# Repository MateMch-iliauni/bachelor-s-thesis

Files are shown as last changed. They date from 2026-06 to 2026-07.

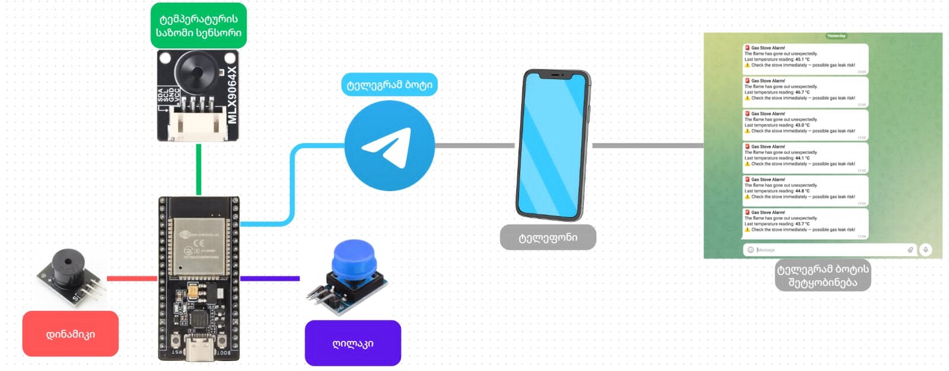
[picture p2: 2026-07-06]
final-website/assets/architecture.jpg

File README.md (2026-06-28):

# გაზქურის მონიტორინგის სისტემა

ეს არის "გაზქურის მონიტორინგის სისტემა"-ის ოფიციალური რეპოზიტორია,  საბაკალავრო ნაშრომი 2025-2026. სისტემა შექმნილია გაზქურის უსაფრთხოების მონიტორინგისა და დისტანციური შეტყობინებების მართვისთვის.

## პროექტის სტრუქტურა

რეპოზიტორია ორგანიზებულია შემდეგი საქაღალდეების მიხედვით:

- `Project-Codes/`: შეიცავს ESP32-S-ზე გაშვებულ firmware-ს, მათ შორის თერმული კამერის ღილაკის და ბაზერის მართვისა და Telegram bot-ის ლოგიკას.
- `project-diagrams/`: სისტემის არქიტექტურის დიაგრამები.
- `Production_drawings/`: პროექტის ტექნიკური ნახაზები და CAD ფაილები.
- `documentation/`: დოკუმენტაცია, მომხმარებლის სახელმძღვანელო.
- `Final-Presentation/`: საბოლოო პრეზენტაცია.
- `Attachments/`: დამატებითი ტექნიკური მასალები და კვლევითი ფაილები.

## სისტემის მახასიათებლები
- **აპარატურა:** ESP32-S მიკროკონტროლერი, 3-პინიანი KY-012 აქტიური ბაზერი თერმული კამერა და ღილაკი.
- **პროგრამული ლოგიკა:** თერმული კამერა, ბაზერი და Telegram bot-ის ლოგიკა გადანაწილებულია მრავალბირთვიან პროცესორზე.
- **ინტერფეისი:** დისტანციური შეტყობინებების მიღება Telegram Bot API-ს მეშვეობით.

## ავტორები
- მათე მჭედლიშვილი
- დათო ქადარია

---
*შექმნილია 2026 წელს, ილიას სახელმწიფო უნივერსიტეტის ფარგლებში.*

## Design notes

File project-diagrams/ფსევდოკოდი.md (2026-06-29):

// — გლობალური ცვლადები —
STATES = { IDLE, MONITORING, FIRE_ACTIVE, ALARM }
state ← IDLE
CONST FIRE_ON	<- 80°C
CONST FIRE_OFF	<- 55°C
CONST COLD_FRAMES_REQUIRED    	<- 8       // ~4 წმ @ 2 Hz
CONST COOLING_FRAMES_REQUIRED 	<- 10     // ~5 წმ @ 2 Hz
CONST COOLING_DELTA	<- -0.2°C
CONST BEEP_INTERVAL	<- 10 წმ

// — ინიციალიზაცია —
PROCEDURE Setup():
    init Serial, Buzzer(OFF), Button(INPUT_PULLUP)
    create tempQueue, alertQueue
    recover I2C bus
    IF NOT sensor.begin() THEN halt forever  // შეცდომა
    configure sensor (CHESS, 18-bit, 2 Hz)
    Setup_WiFi() // WiFiManager პორტალი -> დაკავშირება ან offline
    start task SensorTask   on core 1
    start task TelegramTask on core 0

// — მთავარი ნაკადი —
PROCEDURE Loop():
    Update_Buzzer() // ავტომატურად გამორთვა 500 მილიწამის შემდეგ
    IF Button_Pressed() THEN // debounce (20 მილიწამი)
        Stop_Buzzer()
        state ← (state == IDLE) ? MONITORING : IDLE
        reset counters and queues
        RETURN
    IF state == IDLE THEN RETURN
    IF NOT tempQueue.receive(maxTemp) THEN RETURN   // ახალი frame არ არის

    SWITCH state:
        CASE MONITORING:
            IF maxTemp ≥ FIRE_ON THEN
                state ← FIRE_ACTIVE
                peakTemp ← maxTemp ;  previousTemp ← maxTemp
                reset coldFrameCount, coolingFrames

        CASE FIRE_ACTIVE:
            peakTemp ← max(peakTemp, maxTemp)
            delta ← maxTemp − previousTemp
            IF delta ≤ COOLING_DELTA THEN coolingFrames++ ELSE coolingFrames ← 0
            previousTemp ← maxTemp

            // პირობა 1: მკვეთრი ვარდნა ზღვარს ქვემოთ
            IF maxTemp < FIRE_OFF THEN
                coldFrameCount++
                IF coldFrameCount ≥ COLD_FRAMES_REQUIRED THEN Raise_Alarm(maxTemp)
            ELSE
                coldFrameCount ← 0
            // პირობა 2: თანდათანობითი გაგრილების ტენდენცია (ცხელი ჭურჭელი)
            IF coolingFrames ≥ COOLING_FRAMES_REQUIRED THEN Raise_Alarm(maxTemp)

        CASE ALARM:
            IF (now − lastAlertTime) ≥ BEEP_INTERVAL THEN
                Start_Buzzer() ;  Trigger_Alert(maxTemp)   // განმეორებითი შეხსენება

PROCEDURE Raise_Alarm(t):
    state ← ALARM ;  lastAlertTime ← now
    Start_Buzzer()
    Trigger_Alert(t) // t ჩაიწერება alertQueue-ში

// — სენსორის ნაკადი (ბირთვი 1) —
TASK SensorTask():
    LOOP forever:
        IF state == IDLE THEN wait 50 ms ; CONTINUE
        IF sensor.getFrame(frame) fails THEN wait 20 ms ; CONTINUE
        maxT ← max(frame[0 … 767])           // 32×24 პიქსელის უმაღლესი მნიშვნელობა
        tempQueue.overwrite(maxT)           // ყოველთვის უახლესი კადრი
        wait 10 ms

// ── Telegram-ის ნაკადი (ბირთვი 0) ──
TASK TelegramTask():
    LOOP forever:
        IF alertQueue.receive(alert) THEN
            IF WiFi connected THEN
                bot.sendMessage(chatID, alarm_text(alert.temp))   // HTTPS/TLS
        wait 50 ms

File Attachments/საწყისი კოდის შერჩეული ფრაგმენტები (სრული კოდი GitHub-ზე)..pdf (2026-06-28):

ამ დანართში მოცემულია სისტემის საწყისი კოდის ყველაზე მნიშვნელოვანი ფრაგმენტები -სტატუსების უსაფრთხო მართვა (thread-safe getState/setState), სენსორისა და Telegram-ის ნაკადები (tasks) და ცეცხლის ჩაქრობის ამოცნობის ლოგიკა - მოკლე განმარტებებით. სრული კოდი ხელმისაწვდომია GitHub-ზე.

## სისტემის ძირითადი პარამეტრები

ქვემოთ მოცემულია ის ძირითადი პარამეტრები, რომელთა საფუძველზეც მუშაობს სისტემა: ცეცხლის ანთება/ჩაქრობის ტემპერატურული ზღვრები, ცეცხლის ჩაქრობის დასადასტურებლად საჭირო კადრების (frame-ების) რაოდენობა და Telegram-ზე შეტყობინების გასაგზავნად საჭირო მონაცემები.

const float | FIRE_ON_THRESHOLD = 80.0f;
const float | FIRE_OFF_THRESHOLD = 55.0f;
const int | COLD_FRAMES_REQUIRED = 8;
const int | COOLING_FRAMES_REQUIRED = 10;
const float | COOLING_DELTA_THRESHOLD = -0.2f;
const unsigned long BEEP_INTERVAL_MS = 10000UL; const unsigned long BEEP_DURATION_MS = 500UL;
const char* | TELEGRAM_BOT_TOKEN =
"7655520460:AAG239a4LqNq0acoINI3Pn9RyacG_6AhRUc";
String | TELEGRAM_CHAT_ID = "8154736889";

## სისტემის სტატუსები (state-ები) და ნაკადებზე უსაფრთხო წვდომა

ეს ფრაგმენტი წარმოადგენს პროგრამის ნაკადების (tasks) უსაფრთხო მართვის მექანიზმს.
სისტემას აქვს ოთხი სტატუსი (state): | უმოქმედობა (IDLE), | მონიტორინგი
(MONITORING), ცეცხლის დაფიქსირება (FIRE_ACTIVE) და განგაში (ALARM). ცვლადი currentState ინახავს მიმდინარე სტატუსს, getState() კითხულობს მას, ხოლო setState() უსაფრთხოდ ცვლის ერთ მდგომარეობას მეორით. stateMux კი კრძალავს ორი ნაკადის ერთდროულ წვდომას ამ ცვლადზე და ამით გამორიცხავს მონაცემთა კონფლიქტს - ეს მიიღწევა portENTER_CRITICAL() და portEXIT_CRITICAL() ფუნქციებით.

enum SystemState { STATE_IDLE, STATE_MONITORING, STATE_FIRE_ACTIVE, STATE_ALARM };

static SystemState currentState = STATE_IDLE;
static portMUX_TYPE stateMux = portMUX_INITIALIZER_UNLOCKED;

inline SystemState getState() { SystemState s;
portENTER_CRITICAL(&stateMux); s = currentState;
portEXIT_CRITICAL(&stateMux);
return s;
}

## თერმული კამერის მუშაობის მექანიზმი

სენსორის ფუნქცია გაშვებულია პროცესორის მეორე ბირთვზე (Core 1). იგი კითხულობს 768-პიქსელიან (32×24) ტემპერატურულ მატრიცას, პოულობს მასში მაქსიმალურ მნიშვნელობას და გადასცემს მას სისტემის ძირითად მაკონტროლებელ ლოგიკას რიგის (queue) მეშვეობით.

inline void setState(SystemState s) {
portENTER_CRITICAL(&stateMux);
currentState = s;
portEXIT_CRITICAL(&stateMux); }

void sensorTask(void* parameter) { while (true) {
if (getState() == STATE_IDLE) { vTaskDelay(50 / portTICK_PERIOD_MS); continue;
}

if (mlx.getFrame(sensorFrame) != 0) { Serial.println("[SENSOR] Frame read failed – retrying."); vTaskDelay(20 / portTICK_PERIOD_MS);
continue;
}

float maxT = sensorFrame[0];
for (int i = 1; i < 32 * 24; i++)
if (sensorFrame[i] > maxT) maxT = sensorFrame[i];

xQueueReset(tempQueue);

xQueueSend(tempQueue, &maxT, 0);

vTaskDelay(10 / portTICK_PERIOD_MS);
}
}

## ცეცხლის უეცარი ჩაქრობის ან ტემპერატურის თანდათანობითი ვარდნის დაფიქსირება

სისტემა ცეცხლის ჩაქრობას აფიქსირებს ორი პარალელური მეთოდით: (1) თუ ტემპერატურა ჩამოსცდება 55°C-ს; და (2) თუ ჭურჭელი ცხელ ტემპერატურას ინარჩუნებს, თუმცა შეინიშნება გაგრილების ტენდენცია: კადრებს შორის ტემპერატურის ვარდნა არის 0.2°C ან მეტი ზედიზედ რამდენიმე კადრის განმავლობაში.

case STATE_FIRE_ACTIVE: {
if (maxTemp > peakTemp) peakTemp = maxTemp;

float delta = maxTemp - previousTemp;

if (delta <= COOLING_DELTA_THRESHOLD) { coolingFrames++;
} else {
coolingFrames = 0;
}

previousTemp = maxTemp;

if (maxTemp < FIRE_OFF_THRESHOLD) { coldFrameCount++;
if (coldFrameCount >= COLD_FRAMES_REQUIRED) { setState(STATE_ALARM);
lastAlertTime = millis();
startBuzzer();
triggerAlert(maxTemp);
}
} else {
if (coldFrameCount > 0) {
coldFrameCount = 0;
}
}

if (coolingFrames >= COOLING_FRAMES_REQUIRED) { setState(STATE_ALARM);
lastAlertTime = millis();
startBuzzer();
triggerAlert(maxTemp);
}

break;
}

## Telegram-შეტყობინების გაგზავნა

შეტყობინების გაგზავნის ფუნქცია გაშვებულია პროცესორის პირველ ბირთვზე (Core 0) და დამოუკიდებლად ამუშავებს Telegram API-ის მოთხოვნებს. ამის წყალობით, თერმული კამერიდან მიღებული მონაცემების დამუშავება არ ფერხდება შეტყობინების გაგზავნის დროს.

void telegramTask(void* parameter) {
AlertData alert;
while (true) {
if (xQueueReceive(alertQueue, &alert, 0) == pdTRUE) { if (WiFi.status() == WL_CONNECTED) {
WiFiClientSecure localClient;
localClient.setInsecure();
UniversalTelegramBot bot(TELEGRAM_BOT_TOKEN, localClient);

String message = "🚨 *Gas Stove Alarm!*\n";
message += "The flame has gone out unexpectedly.\n";
message += "Last temperature reading: *" + String(alert.temp, 1) + " °C*\n"; message += "⚠️ Check the stove immediately — possible gas leak risk!";

Serial.println("[Telegram] Sending alert…"); bot.sendMessage(TELEGRAM_CHAT_ID, message, "Markdown"); Serial.println("[Telegram] Alert sent.");
} else {
Serial.println("[Telegram] Skipped – no Wi-Fi.");
}
}

vTaskDelay(50 / portTICK_PERIOD_MS); }
}

სრული კოდის github-ის ბმული: https://github.com/MateMch-iliauni/Project-Codes/blob/main/finalproject.ino

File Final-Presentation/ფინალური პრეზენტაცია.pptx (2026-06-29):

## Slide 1

გაზქურის მონიტორინგის სისტემა

დამამთავრებელი კურსის დიზანის პროექტი

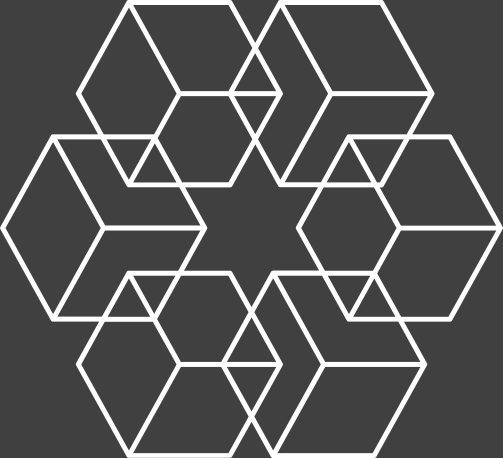
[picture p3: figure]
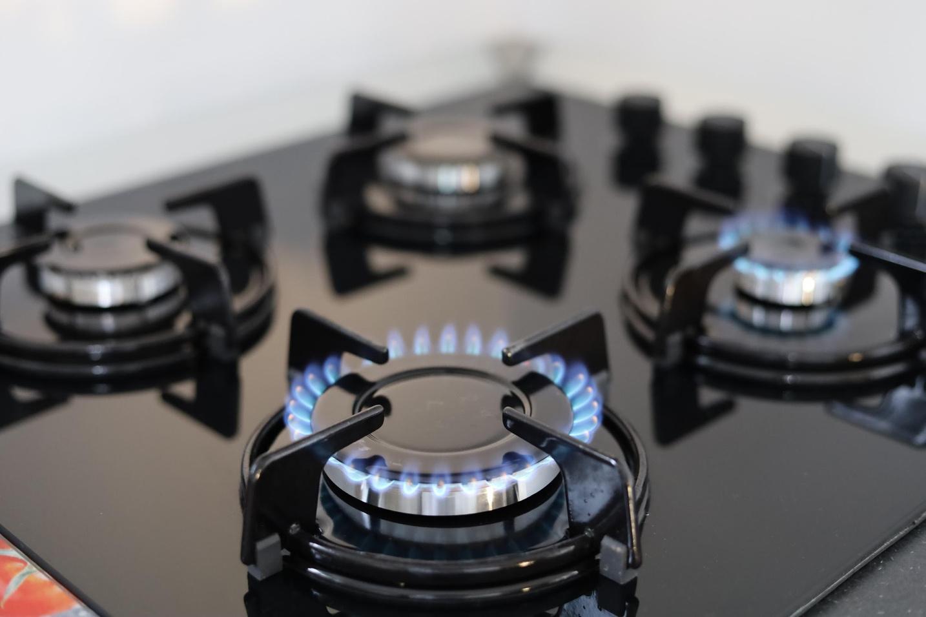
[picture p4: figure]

კურსის ხელმძღვანელები:
დავით ჩხაიძე
გიორგი მოდებაძე

ჯგუფის წევრები:
დათო ქადარია
მათე მჭედლიშვილი

1

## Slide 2

შევქმენით გაზქურის მონიტორინგის სისტემა, რომელიც თერმული კამერის გამოყენებით აღმოაჩენს ცეცხლის ჩაქრობას და მყისიერად ატყობინებს მომხმარებელს დინამიკისა და Telegram-ის მეშვეობით.

პროექტის მიმოხილვა

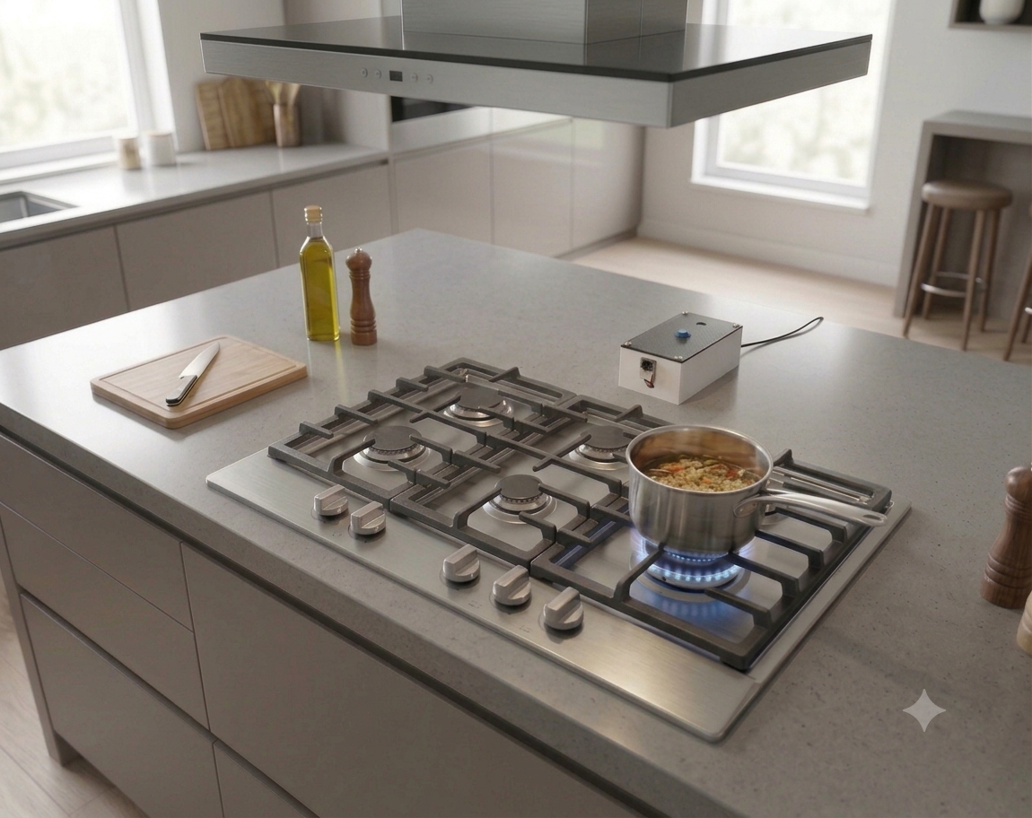
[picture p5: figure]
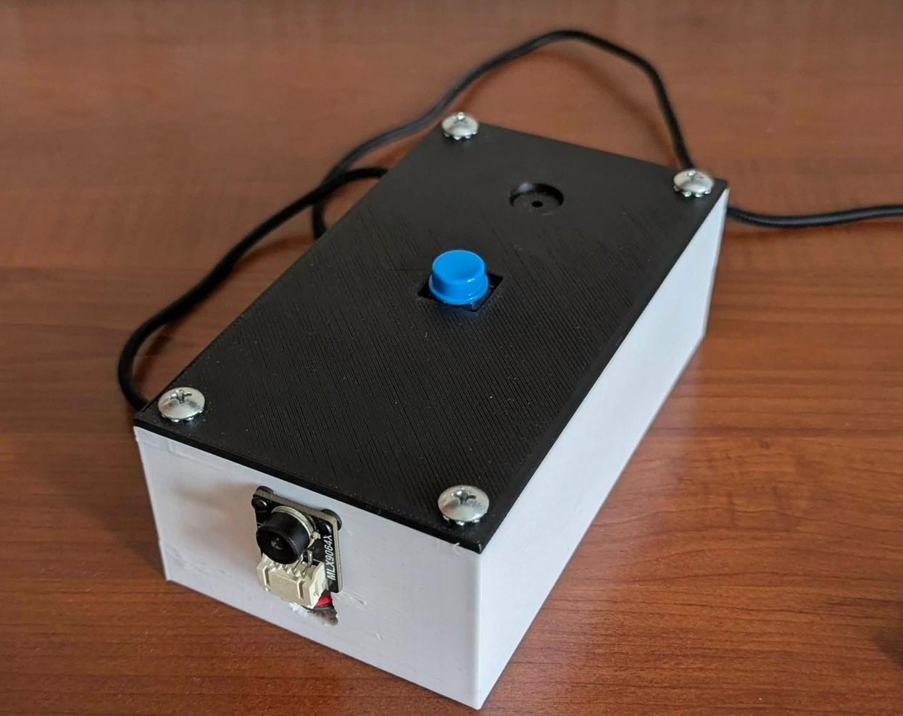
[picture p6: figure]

2

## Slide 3

ბლოკდიაგრამა

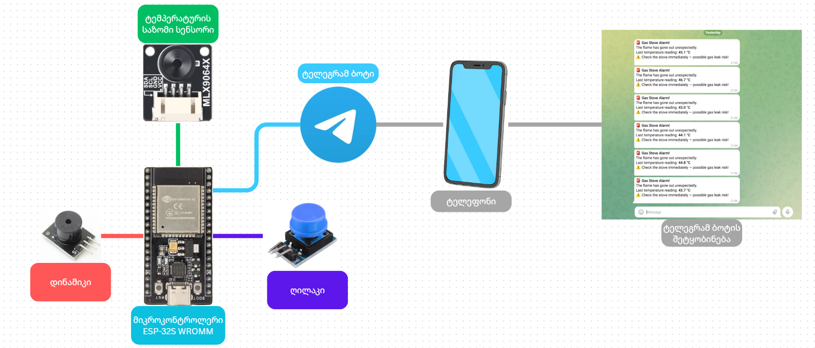
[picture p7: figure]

4

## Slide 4

ტემპერატურის სენსორი

MLX90640
    - თერმული კამერა, 110° ხედვის კუთხით, ზომავს -40℃～300℃
    - იყენებს I²C ინტერფეისს, რაც შესაძლებელს ხდის მის ინტეგრირებას ESP32

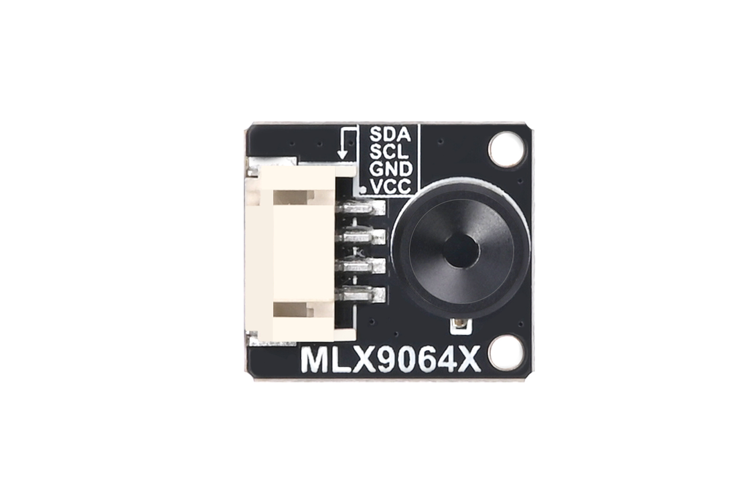
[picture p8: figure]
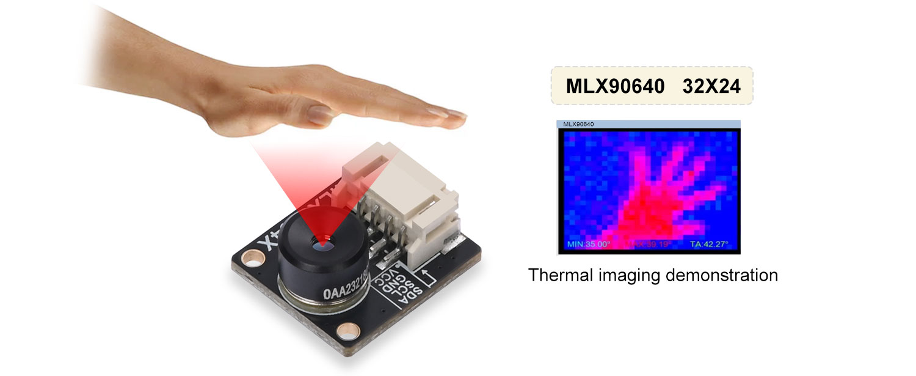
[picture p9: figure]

5

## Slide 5

ESP-32S WROOM
    - კომპაქტური და ძლიერი, მრავალფუნქციური მიკროკონტროლერი
    - უკაბელო კავშირის (Wi-Fi და Bluetooth) შესაძლებლობების მქონე მოწყობილობა, რომელიც ასევე გამორჩეულია ენერგოეფექტურობით.

მიკროკონტროლერი

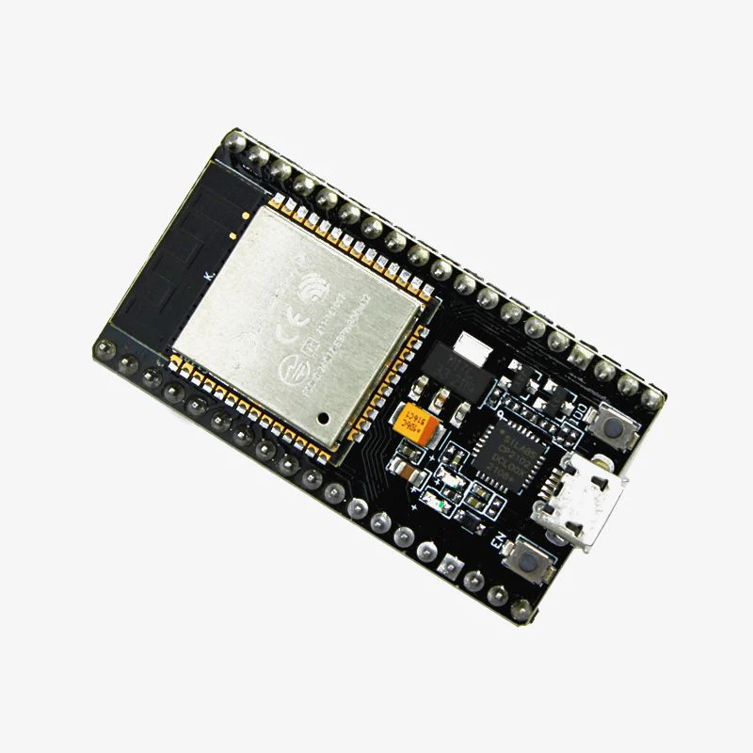
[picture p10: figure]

8

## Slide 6

    - კომპაქტური active buzzer-ი, რომელიც ჩართვისას გამოსცემს ფიქსირებული სიხშირის (~85 dB) სიგნალს, რაც საკმაოდ ეფექტურია ლოკალური შეტყობინებისთვის.

დინამიკი

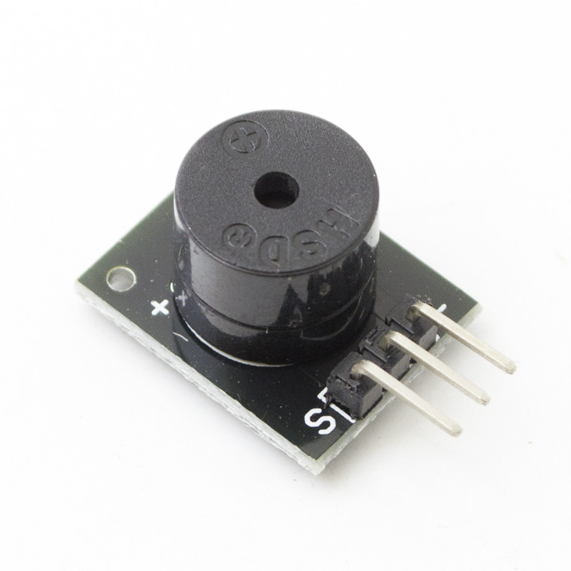
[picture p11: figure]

9

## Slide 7

  - ღილაკი აფიქსირებს დაჭერას და გადასცემს სიგნალს მიკროკონტროლერს, რითაც მოხდება სისტემის მართვა.

ღილაკი

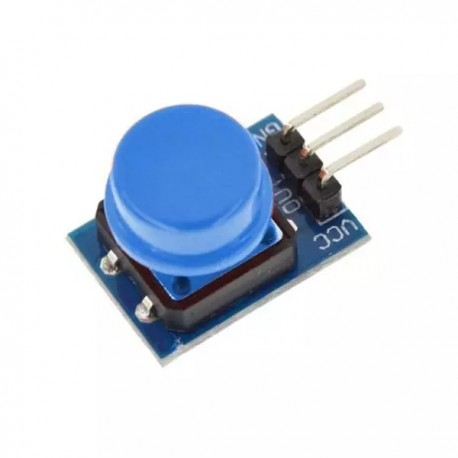
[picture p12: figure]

9

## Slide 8

3D დიზაინი, თერმული კამერა, დინამიკი, ღილაკი და მიკრო კონტროლერი ქმნის სრულ მოწყობილობას “გაზქირის მონიტორნიგის სისტემა”

პროტოტიპი

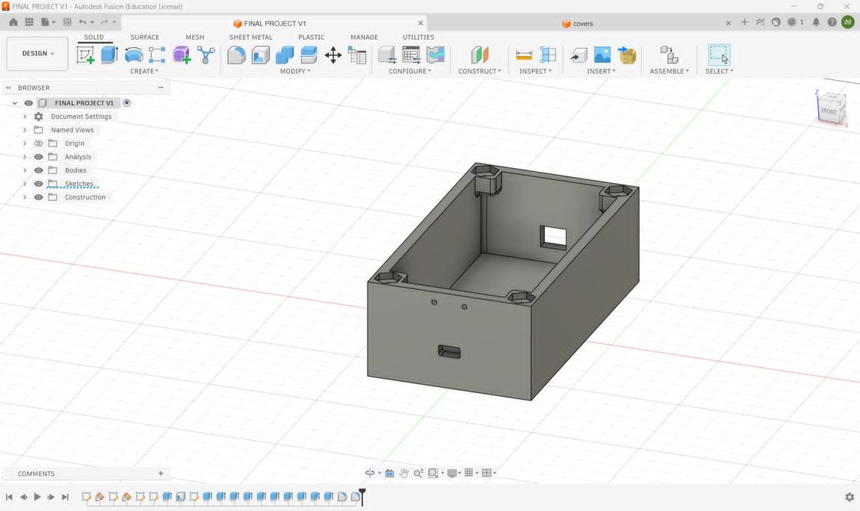
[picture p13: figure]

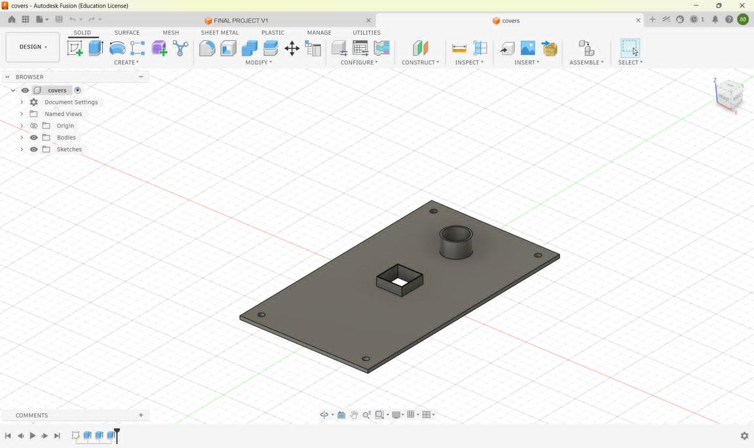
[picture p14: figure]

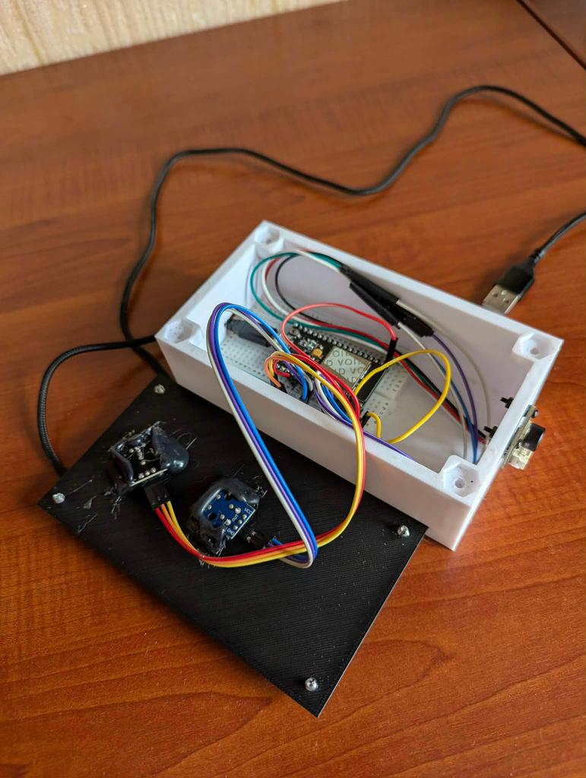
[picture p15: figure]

12

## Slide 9

მოქმედების მექანიზმი

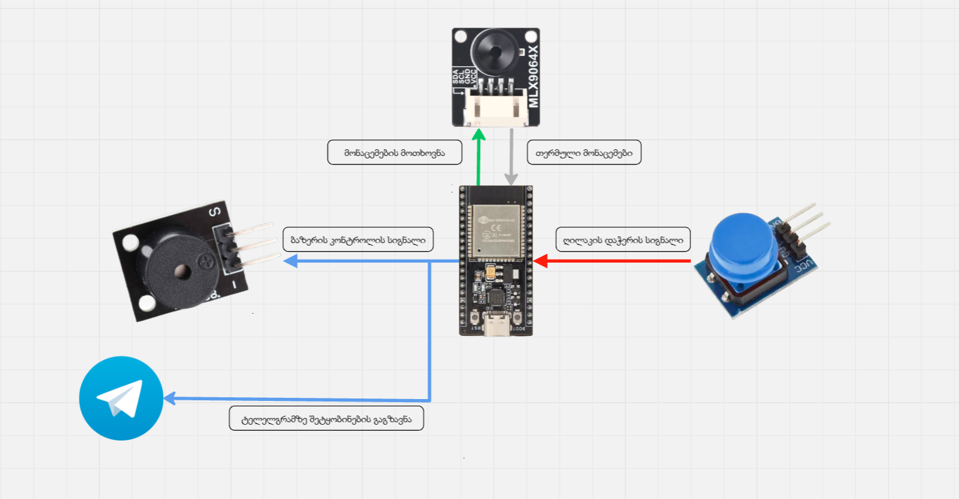
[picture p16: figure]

11

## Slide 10

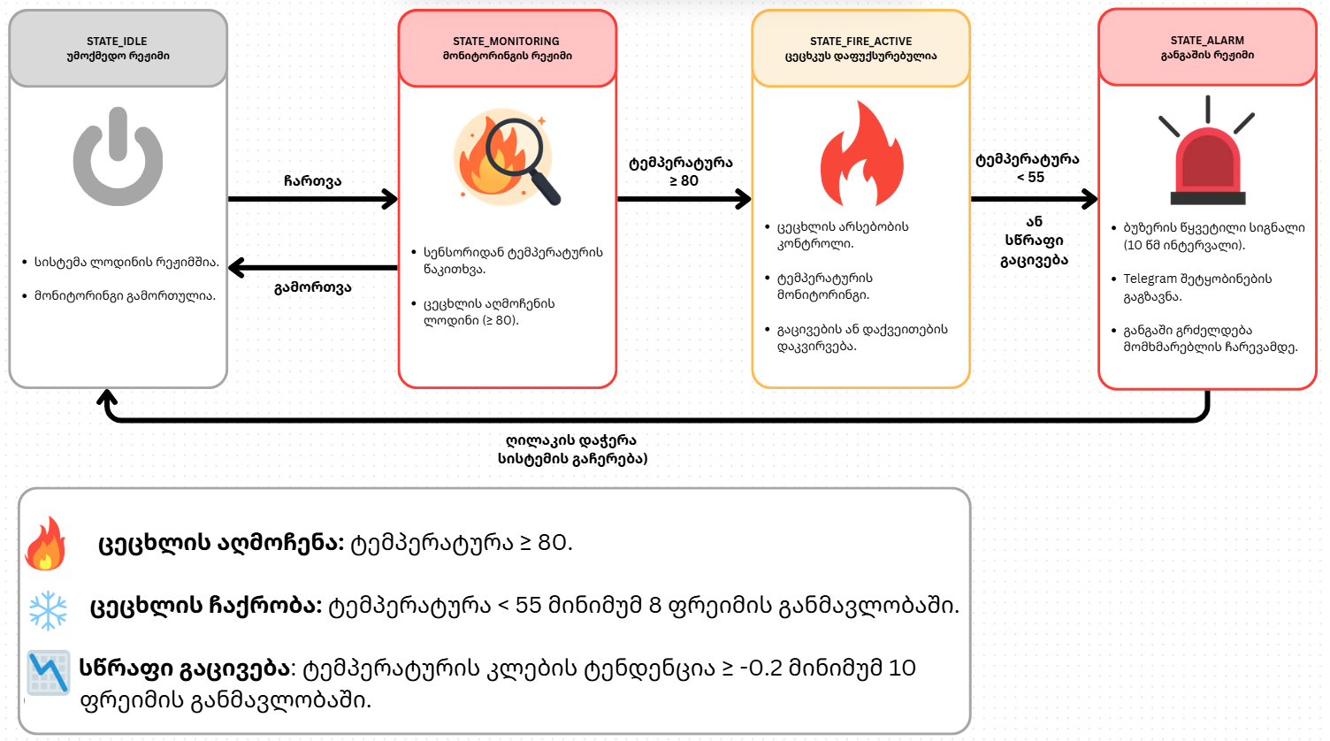
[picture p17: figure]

11

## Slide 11

პროექტის დოკუმენტაციის ოფიციალური ვებ-გვერდი, სადაც ხელმისაწვდომია სრული ინფორმაცია პროექტის შესახებ.

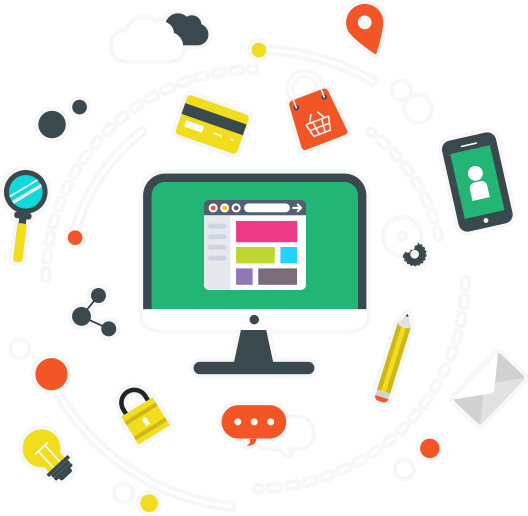
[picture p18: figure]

- https://bachelor-s-thesis-topaz.vercel.app

ვებგვერდი

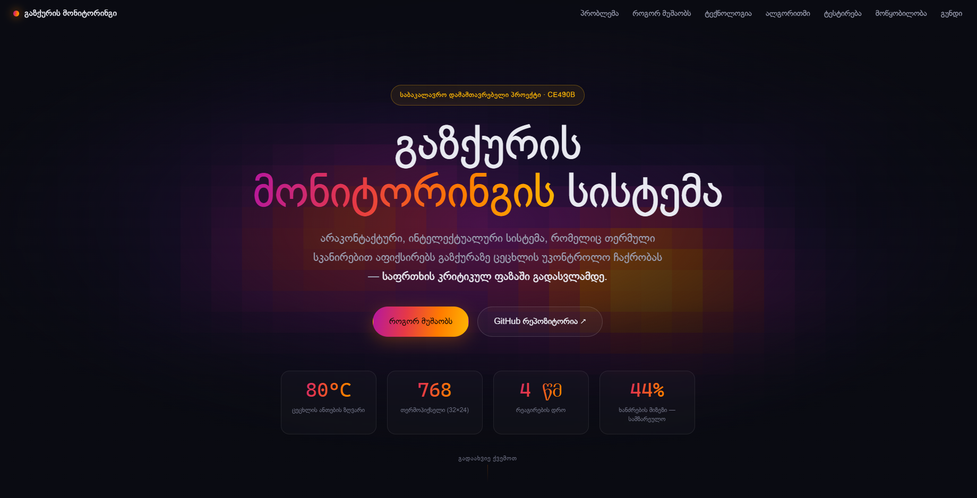
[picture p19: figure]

22

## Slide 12

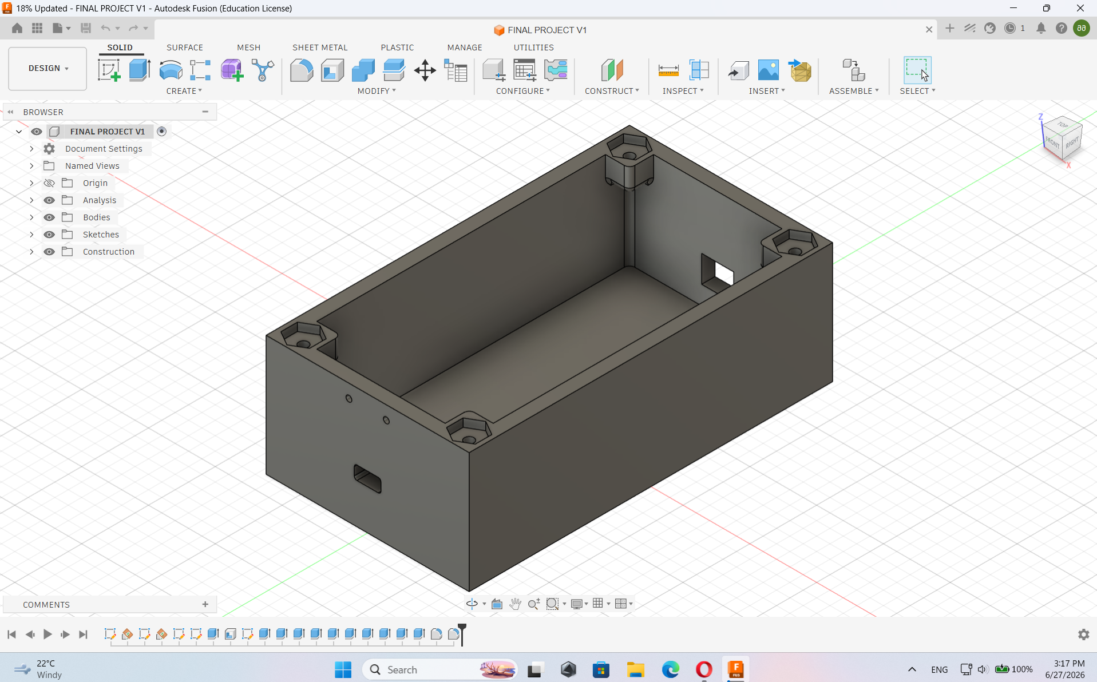
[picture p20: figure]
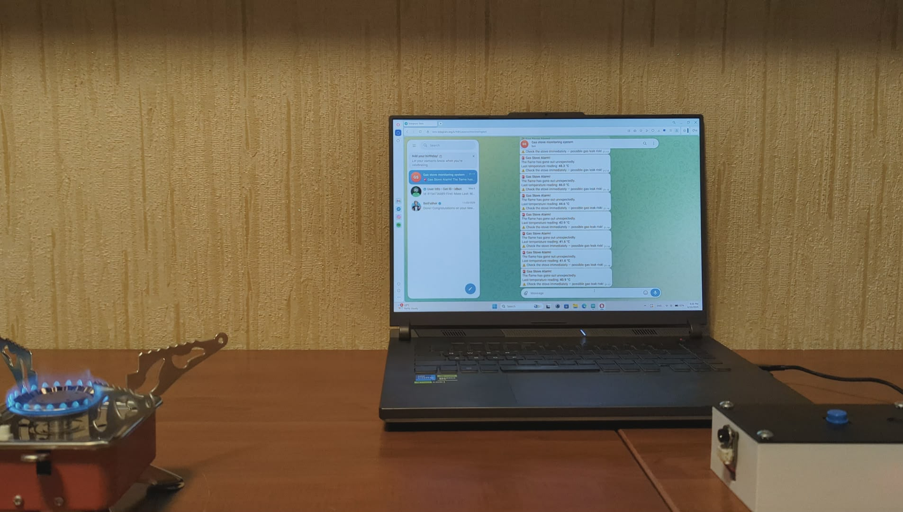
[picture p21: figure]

შეჯამება

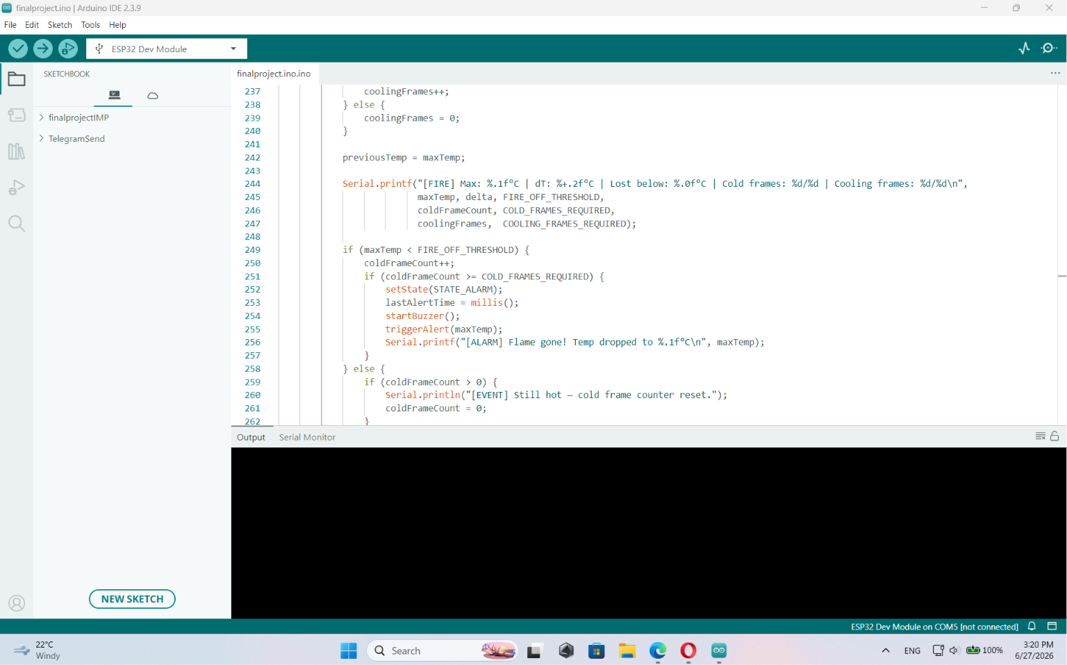
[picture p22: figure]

20

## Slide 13

მადლობა ყურადღებისთვის

25

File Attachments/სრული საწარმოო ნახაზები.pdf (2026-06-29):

### 3D მოდელები და მათი საწარმოო ნახაზები

ამ დანართში მოცემულია პროექტის კორპუსის Autodesk Fusion 360-ში შემუშავებული 3D მოდელები და მათი ნახაზები. სრული, რედაქტირებადი ფაილები ხელმისაწვდომია GitHub-ზე.

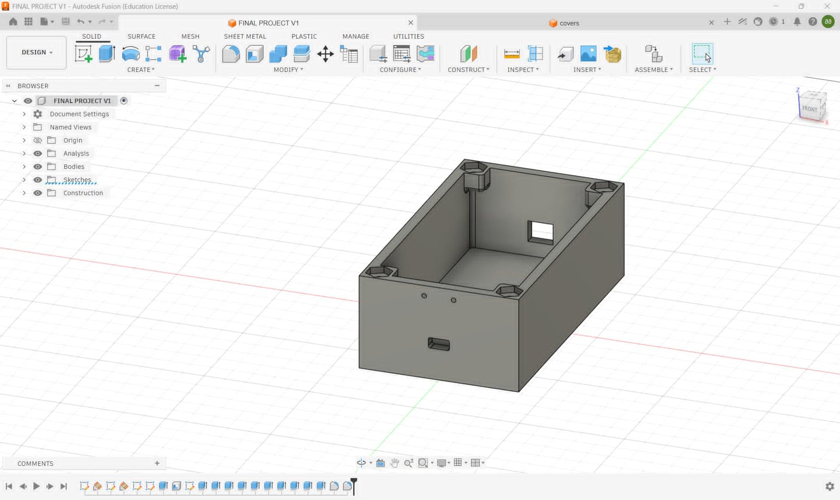
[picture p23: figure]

მოწყობილობის კორპუსის 3D მოდელი და მისი საწარმოო ნახაზი

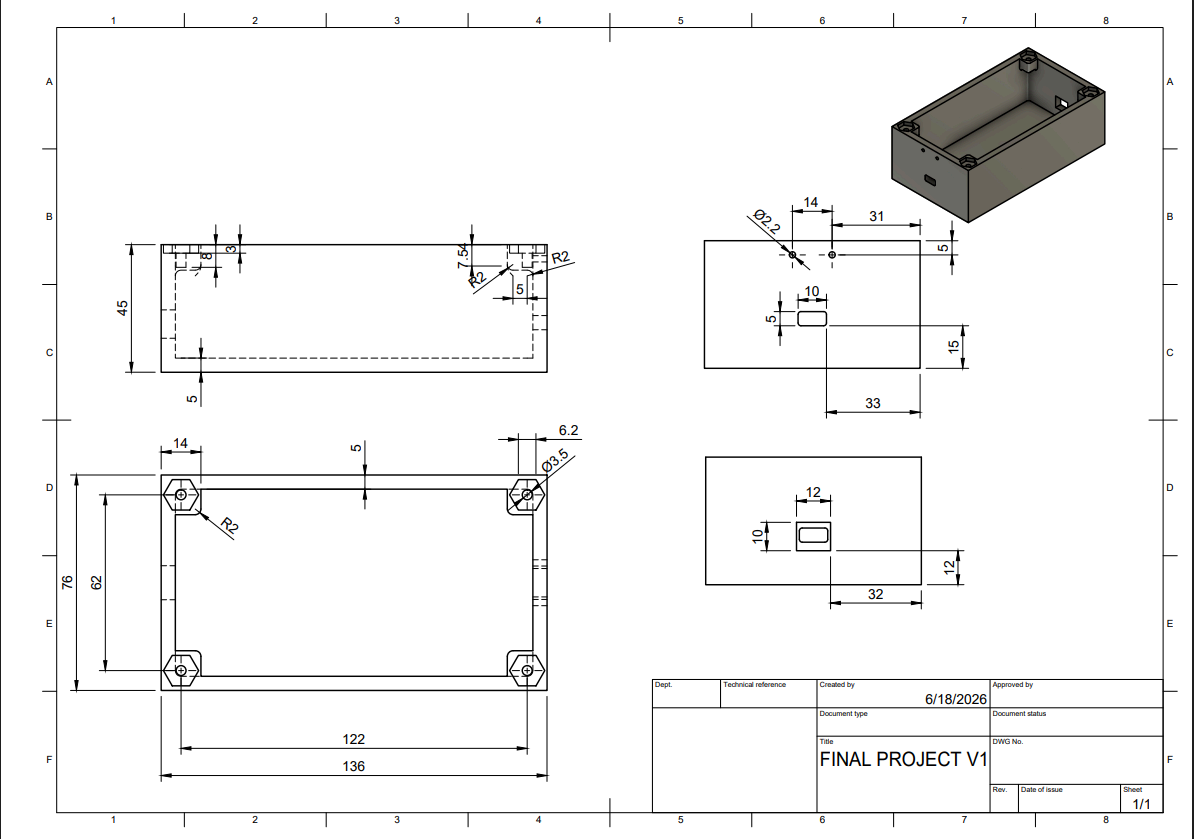
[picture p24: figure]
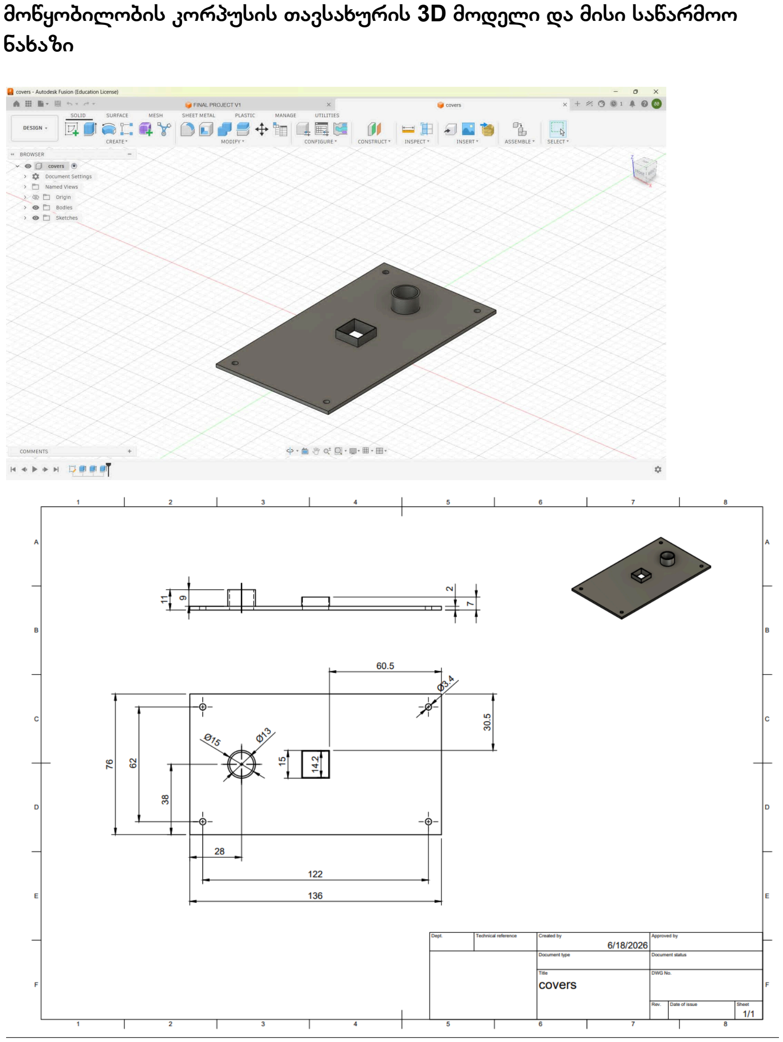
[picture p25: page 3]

მოწყობილობის კორპუსის თავსახურის 3D მოდელი და მისი საწარმოო ნახაზი საწრმოო ნახზების Github-ის
ლინკი:https://github.com/MateMch-iliauni/Production_drawings

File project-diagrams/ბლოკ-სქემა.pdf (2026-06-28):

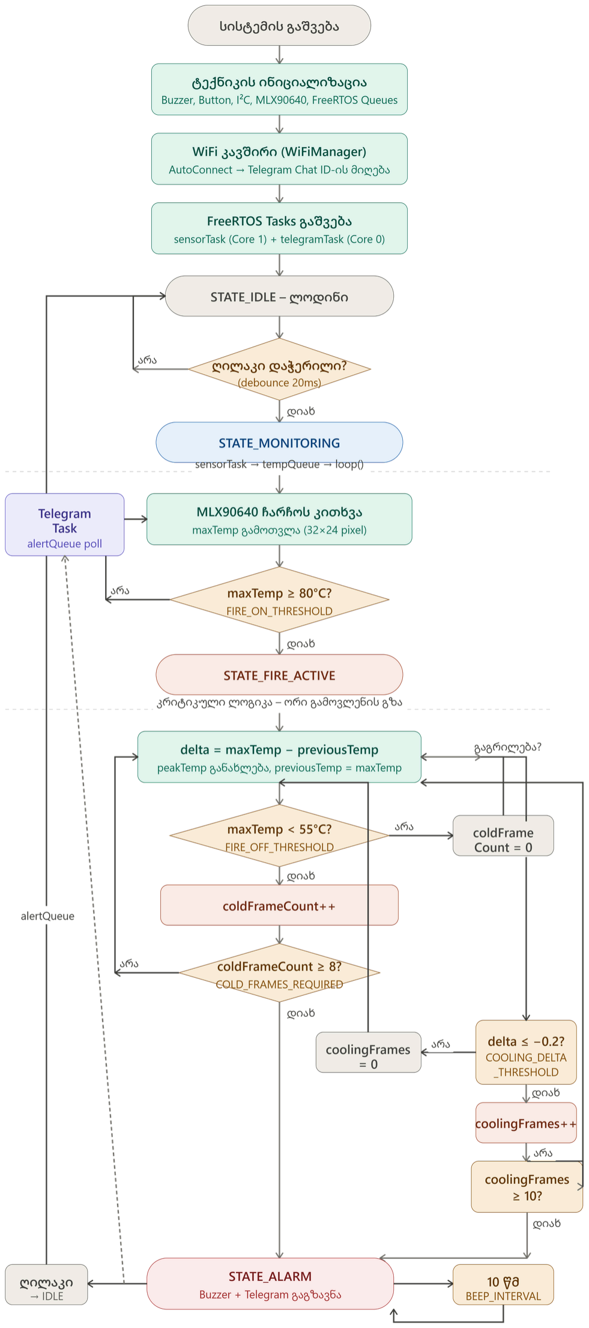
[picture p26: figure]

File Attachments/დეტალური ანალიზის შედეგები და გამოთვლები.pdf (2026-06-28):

ამ დანართში მოცემულია ოთხი ალტერნატიული ექსპერიმენტული სცენარი. თითოეული მათგანი ასახავს სისტემის მუშაობის მაგალითს რეალურ პირობებში და მოიცავს ეტაპობრივ ცხრილებსა და ტემპერატურულ-დროით გრაფიკებს.

სცენარი 1 - ცეცხლის არსებობის და ჩაქრობის იდენტიფიკაცია

ალის იდენტიფიცირება ხორციელდება პროგრამულად განსაზღვრული ზღვრული ტემპერატურული მაჩვენებლების საფუძველზე. ალის ამოცნობის ზღვრად ემპირიული ტესტირების შედეგად განისაზღვრა 80°C. მიუხედავად იმისა, რომ უშუალოდ სანთურაზე ალის ტემპერატურა 100°C-ს საგრძნობლად აჭარბებს, 80°C წარმოადგენს ოპტიმალურ და უსაფრთხო ზღვარს. იგი გამორიცხავს ცრუ განგაშს (რაც შეიძლება გამოიწვიოს გარემოში არსებული ობიექტების სითბური გამოსხივების არეკვლამ) და ამავდროულად, დროულად აფიქსირებს საფრთხეს, რადგან ოთახის ტემპერატურის პირობებში გარემომცველი ობიექტები ამ ნიშნულს ბუნებრივად ვერ აღწევენ.

ალის ჩაქრობის ქვედა ზღვრად განისაზღვრა 55°C. ექსპერიმენტებმა აჩვენა, რომ სანთურის ჩაქრობისთანავე ტემპერატურა სწრაფად ეცემა 50°C - 60°C დიაპაზონში. 80°C-სა და 55°C-ს შორის არსებული შუალედი წარმოადგენს ბუფერულ ზონას, რაც მინიმუმამდე ამცირებს სისტემის არასტაბილურ გადართვებსა და ცრუ განგაშის ალბათობას.

პროგრამაში ასევე გათვალისწინებულია მეორე მეთოდი ცეცხლის ჩაქრობის დასაფიქსირებლად, რომელიც აკვირდება ტემპერატურის თანდათანობითი კლების ტენდენციას. აღნიშნული მეთოდი დაგვჭირდა, რადგან ობიექტები, როგორიცაა ქვაბი ან ტაფა საკმაოდ კარგად ინარჩუნებენ ტემპერატურას და ცდების შედეგადაც გამოჩნდა, რომ ასეთ შემთხვევებში ტემპერატურა მცირდება თანდათანობით და არა მყისიერად.

სცენარი 2 - ცეცხლის ჩაქრობის დაფიქსირება გაზქურის სანთურაზე

ცდის ჩატარების შედეგად წარმატებით დაფიქსირდა ტემპერატურის ვარდნა და ცეცხლის ჩაქრობა. ამ შემთხვევაში იმუშავა ზღვრული ტემპერატურული მნიშვნელობების მეთოდმა, რადგან გაზის სანთურას არ ინარჩუნებს ტემპერატურას მისი შემადგენლობიდან და ფიზიკური პარამეტრებიდან გამომდინარე; ამგვარად, ტემპერატურა სწრაფად, რამდენიმე წამში, ჩამოსცდა ჩვენ მიერ განსაზღვრულ ქვედა ზღვარს - 55 გრადუს, რის შემდეგაც გააქტიურდა ხმოვანი სიგნალი და სისტემამ დაიწყო Telegram-ზე შეტყობინების გაგზავნა პოტენციური საფრთხის შესატყობინებლად.

ეტაპი | მდგომარეობა | მაქსიმალური ტემპერატურა(°C) | განსაზღვრული საზღვრები | სისტემის ქცევა
1 | სისტემის ჩართვა | 35.4 - 36.9 | 80℃ | მონიტორინგის დაწყება
2 | ცეცხლის დაფიქსირება | 90.9 | ≥80℃ | ცეცხლის დაფიქსირება
3 | გაზქურა ანთებულია | 116.7 - 135.3 | >80℃ | მიმდინარე მონიტორინგი ცეცხლის დაფიქსირების შემდეგ
4 | ცეცხლის ჩაქრობა | 62.2 | >55℃ | დაიწყო ტემპერატურამ კლება
5 | საზღვარს ჩამოსცდა | 54.8 | <55℃ | სენსორი ვეღარ ხედავს ცეცხლს
6 | ტემპერატურის სტაბილური შემცირება | 54.7 - 53.7 | Cold frames =+1 | დაფიქსირდა ტემპერატურის კლება მიმდევრობით
7 | ცეცხლის ჩაქრობის დადასტურება | 53.7 | Cold frames = 10 | გააქტიურდა განგაშის მექანიზმი


სცენარი 3 - ცეცხლის ჩაქრობის დაფიქსირება ქვაბის შემთხვევაში

ამ ცდის ჩატარების შედეგადაც წარმატებით იქნა დაფიქსირებული ტემპერატურის ვარდნა და ცეცხლის ჩაქრობა. აქ იმუშავა ტემპერატურის თანდათანობითი ვარდნის დაფიქსირების მეთოდმა. ქვაბს (და ზოგადად, მეტალის ჭურჭელს) აქვს ტემპერატურის შენარჩუნების უნარი მისი შემადგენლობისა და ფიზიკური თვისებებიდან გამომდინარე. მით უმეტეს მაშინ, თუ მასში რაიმე ნივთიერებაა მოთავსებული. მიუხედავად ამისა, ჩვენ მიერ შემუშავებული ალგორითმი, რომელიც აკვირდება ტემპერატურის თანდათანობითი კლების ტენდენციას, წარმატებით ახერხებს ცეცხლის მოულოდნელი ჩაქრობის იდენტიფიცირებას რამდენიმე წამში და რეაგირებს მომხმარებლის შესატყობინებლად და საფრთხის თავიდან ასაცილებლად.

ეტაპი | მდგომარეობა | მაქსიმალური ტემპერატურა(°C ) | განსაზღვრული საზღვრები | სისტემის ქცევა
1 | სისტემის ჩართვა და მონიტორინგის დაწყება | 35.6 - 46.7 | 80℃ | მონიტორინგის დაწყება

2 | ცეცხლის დაფიქსირება | 111.1 | ≥80℃ | ცეცხლის დაფიქსირება
3 | ქვაბის გაცხელება | 118.1 - 168.1 | >80℃ | მიმდინარე მონიტორინგი ცეცხლის დაფიქსირების შემდეგ
4 | ტემპერატურის მაქსიმალური მაჩვენებელი | 168.1 | —----- | დაფიქსირდა მაქსიმალური ტემპერატურა
5 | ქვაბის გაცივების დაწყება | 168.1 - 165.0°C | dT < 0 | მიმდევრობითი ტემპერატურის კლების ტენდენცია
6 | მიმდევრობით სტაბილური გაცივება | 140 - 105.6 | Cooling Frames += 1 | გააქტიურდა განგაშის მექანიზმი
7 | ცეცხლის არარსებობის დადასტურება | 105.6 | Cooling Frames = 10 | განგაშის მდგომარეობაში გადასვლა


სცენარი 4 - ცეცხლის ჩაქრობის დაფიქსირება ტაფის შემთხვევაში

ეს სცენარი ყველაზე კომპლექსურია, რადგან ამ შემთხვევაში ტემპერატურა ძალიან მაღალ ნიშნულს აღწევს. რიგ შემთხვევებში ტემპერატურა აჭარბებს 200℃-ს და ამასთან, ტემპერატურა დიდი ხნით ნარჩუნდება გაზქურის ჩაქრობის შემთხვევაშიც კი. თუმცა, მიუხედავად ამისა, ჩვენი მეორე მეთოდი - ალგორითმი რომელიც აკვირდება ტემპერატურის თანდათანობითი კლების ტენდენციას, ეფექტურად აფიქსირებს საფრთხეს რამდენიმე წამში და ატყობინებს მომხმარებელს.

ეტაპი | მდგომარეობა | მაქსიმალური ტემპერატურა(°C ) | განსაზღვრული საზღვრები | სისტემის ქცევა
1 | სისტემის ჩართვა | 58.0 - 58.7 | 80℃ | მონიტორინგის დაწყება
2 | ცეცხლის დაფიქსირება | 103.8 | ≥80℃ | ცეცხლის დაფიქსირება
3 | ტაფის გაცხელება | 123.9 - 262.8 | >80℃ | მიმდინარე მონიტორინგი ცეცხლის დაფიქსირების შემდეგ
4 | ტემპერატურის მაქსიმალური მაჩვენებელი | 262.8 | —----- | მაქსიმალური ტემპერატურა
5 | გაცივების დაწყება | 258.9 | dT < 0 | დაიწყო ტემპერატურის შემცირება მიმდევრობით
6 | სტაბილური გაცივება მიმდევრობით | 258.9 - 254.4 | Cooling Frames =+1 | გაცივების მიმდევრობითი კადრების დაფიქსირება
7 | ცეცხლის ჩაქრობის დაფიქსირება და განგაშის გააქტიურება | 254.4 | Cooling Frames = 10 | დააფიქსირა ზედიზედ 10 გაცივების კადრი და გააქტიურდა განგაშის სისტემა

ცხრილი 6


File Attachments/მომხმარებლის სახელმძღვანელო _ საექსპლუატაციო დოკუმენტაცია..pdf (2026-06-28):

## მომხმარებლის სახელმძღვანელო

მოწყობილობის მიმოხილვა
გაზქურის მონიტორინგის სისტემა აკვირდება გაზქურის მთლიან ზედაპირს (ოთხივე სანთურას) და ცეცხლის უეცარი ჩაქრობის შემთხვევაში მომენტალურად აფიქსირებს მას. ამის შემდეგ ხმოვანი სიგნალითა და Telegram-ის შეტყობინებით აფრთხილებს მომხმარებელს საფრთხის შესახებ, რათა მან დროული რეაგირება მოახდინოს და თავიდან აიცილოს ხანძრისა და გაზის გაჟონვის რისკი.

პირველადი გაშვება და გამართვა

1. შეაერთეთ მოწყობილობა კვების წყაროსთან.
2. განათავსეთ გაზქურის გვერდით იმგვარად, რომ თერმული კამერა ხედავდეს ოთხივე სანთურას.
3. მოწყობილობა ჩართვისთანავე შექმნის საკუთარ Wi-Fi წვდომის წერტილს სახელით „ThermalSystemSetup“.
4. სმარტფონით | ან | ლეპტოპით | დაუკავშირდით | აღნიშნულ | ქსელს
(„ThermalSystemSetup“).
5. დაკავშირებისთანავე ავტომატურად გაიხსნება მოწყობილობის კონფიგურაციის ვებგვერდი.
6. დააჭირეთ ღილაკს „Configure Device“.
7. შეიყვანეთ შემდეგი მონაცემები:
- თქვენი Wi-Fi ქსელის სახელი (მაგ. wifi1);
- Wi-Fi ქსელის პაროლი (მაგ. password);
- Telegram ჩათის ID (მაგ. 8154736889).
8. შეინახეთ პარამეტრები და დაიცადეთ რამდენიმე წამი, სანამ მოწყობილობა განაახლებს კონფიგურაციას და დაუკავშირდება თქვენს Wi-Fi ქსელს.

კონფიგურაციის შემდეგ სისტემა დაიწყებს გაზქურის მონიტორინგის პროცესს.

ნორმალური მუშაობის სცენარი

ღილაკზე დაჭერის შემდეგ სისტემა იწყებს გაზქურის ზედაპირის თერმული მდგომარეობის მონიტორინგს. მაღალი ტემპერატურის დაფიქსირებისას იგი აღიქვამს ცეცხლის არსებობას და ელოდება მის ჩაქრობას. თუ ამის შემდეგ ტემპერატურა დაბლა დაეცემა, ეს ნიშნავს, რომ ცეცხლი ჩაქრა და სისტემა ააქტიურებს განგაშის მექანიზმს მანამ, სანამ მომხმარებელი ხელახლა არ დააჭერს ღილაკს.

განგაშის მექანიზმი:
- ააქტიურებს ხმოვან სიგნალს;
- აგზავნის შეტყობინებას Telegram-ის აპლიკაციაში;
- აგრძელებს ხმოვანი სიგნალის გამოცემას და Telegram-შეტყობინების გაგზავნას მანამ, სანამ მომხმარებელი ღილაკზე ხელს არ დააჭერს.

მოწყობილობის გამოყენების სახელმძღვანელო

1. ჩართეთ გაზქურა.
2. ღილაკზე დაჭერით ჩართეთ მოწყობილობა.
3. მოწყობილობა იწყებს მონიტორინგს.
4. მაღალი ტემპერატურის დაფიქსირებისას აღიქვამს ცეცხლის არსებობას და ელოდება ტემპერატურის დაცემას.
5. ტემპერატურის დაცემის შემდეგ მოწყობილობა აღიქვამს ცეცხლის ჩაქრობას.
6. გადადის განგაშის რეჟიმში:
- ირთვება ხმოვანი სიგნალი;
- იგზავნება შეტყობინება Telegram-ის აპლიკაციაში.
7. ღილაკზე ხელახალი დაჭერით მომხმარებელი თიშავს მოწყობილობას.

ექსპლუატაციის რეკომენდაციები

- არ დაფაროთ კამერის ხედვის არე და სწორად მიმართეთ ის გაზქურისკენ;
- მოწყობილობა მოათავსეთ მყარ, სტაბილურ ზედაპირზე;
- გამოიყენეთ სტაბილური კვების წყარო;
- მიეცით მოწყობილობას წვდომა თქვენს Wi-Fi ქსელზე;
- პერიოდულად გაწმინდეთ კამერის ლინზა მტვრისა და ჭუჭყისგან.

გაუმართაობის შემთხვევები და მათი გადაჭრის გზები

პრობლემა | შესაძლო მიზეზი | გადაჭრის გზა
Telegram-ზე შეტყობინება არ იგზავნება | არასწორი Telegram Chat ID ან Wi-Fi მონაცემები | გადატვირთეთ მოწყობილობა და თავიდან დააკონფიგურირეთ „ThermalSystemSetup“ ქსელის მეშვეობით
Wi-Fi კონფიგურაციის გვერდი არ იხსნება | მოწყობილობა არ არის სწორ რეჟიმში ან Wi-Fi მენეჯერს აქვს ხარვეზი | გადატვირთეთ მოწყობილობა და თავიდან დაუკავშირდით „ThermalSystemSetup“ ქსელს
მოწყობილობა ვერ იღებს თერმულ მონაცემებს | I²C კომუნიკაციის ხარვეზი თერმულ კამერასთან | გამორთეთ და თავიდან ჩართეთ მოწყობილობა კვების წყაროდან
ღილაკი და სიგნალიზაცია არ მუშაობს | დაერთების (კავშირის) პრობლემა | გადაამოწმეთ, სწორად არის თუ არა მიერთებული ღილაკი GPIO5-ზე და დინამიკი GPIO4-ზე
ცრუ განგაში და შეტყობინების გაგზავნა | კამერის ხედვის კუთხის ცვლილება | გაასწორეთ მოწყობილობის ხედვის არე იმგვარად, რომ ყველა სანთურა მასში მოექცეს

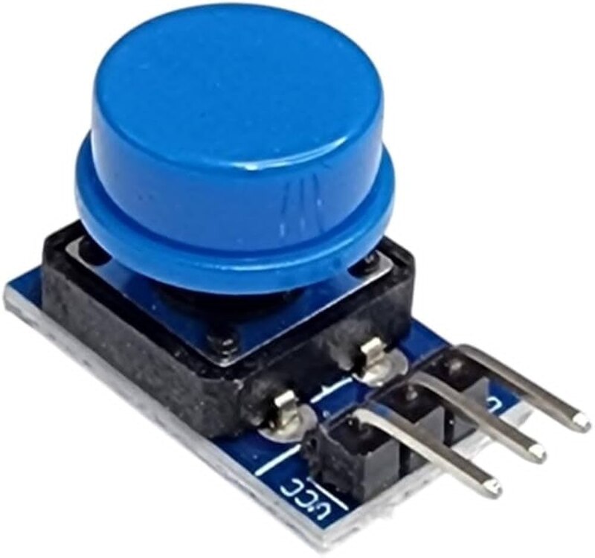
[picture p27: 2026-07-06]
final-website/assets/comp-button.jpg

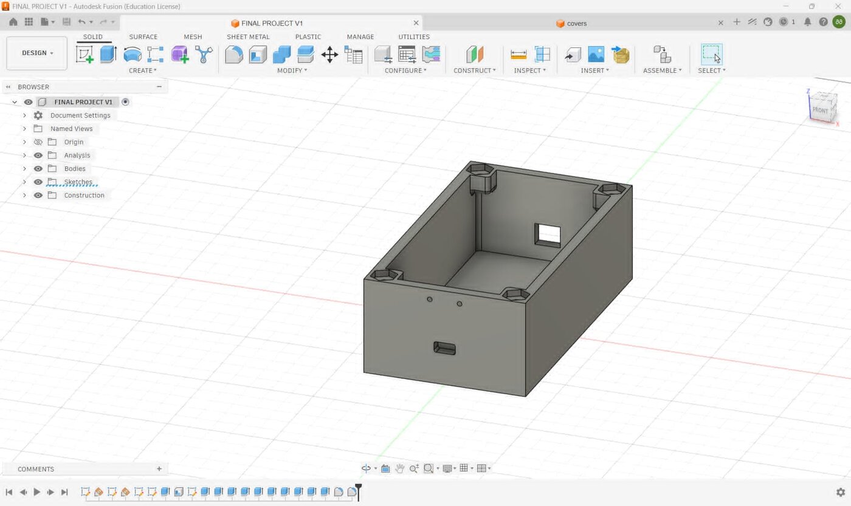
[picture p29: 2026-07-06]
final-website/assets/cad-body.jpg

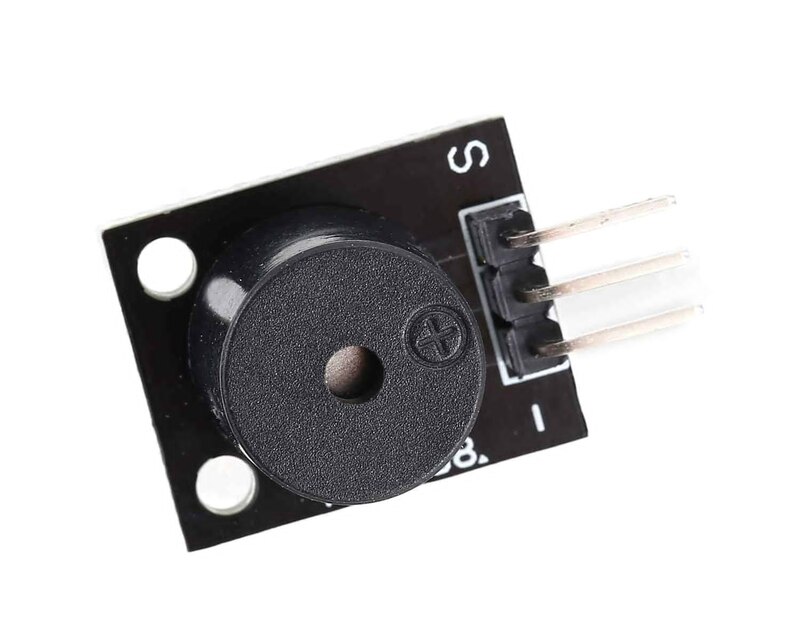
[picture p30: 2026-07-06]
final-website/assets/comp-buzzer.jpg

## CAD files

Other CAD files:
Production_drawings/FINAL PROJECT V1-box.f3d
Production_drawings/FINAL PROJECT V1-cover.f3d

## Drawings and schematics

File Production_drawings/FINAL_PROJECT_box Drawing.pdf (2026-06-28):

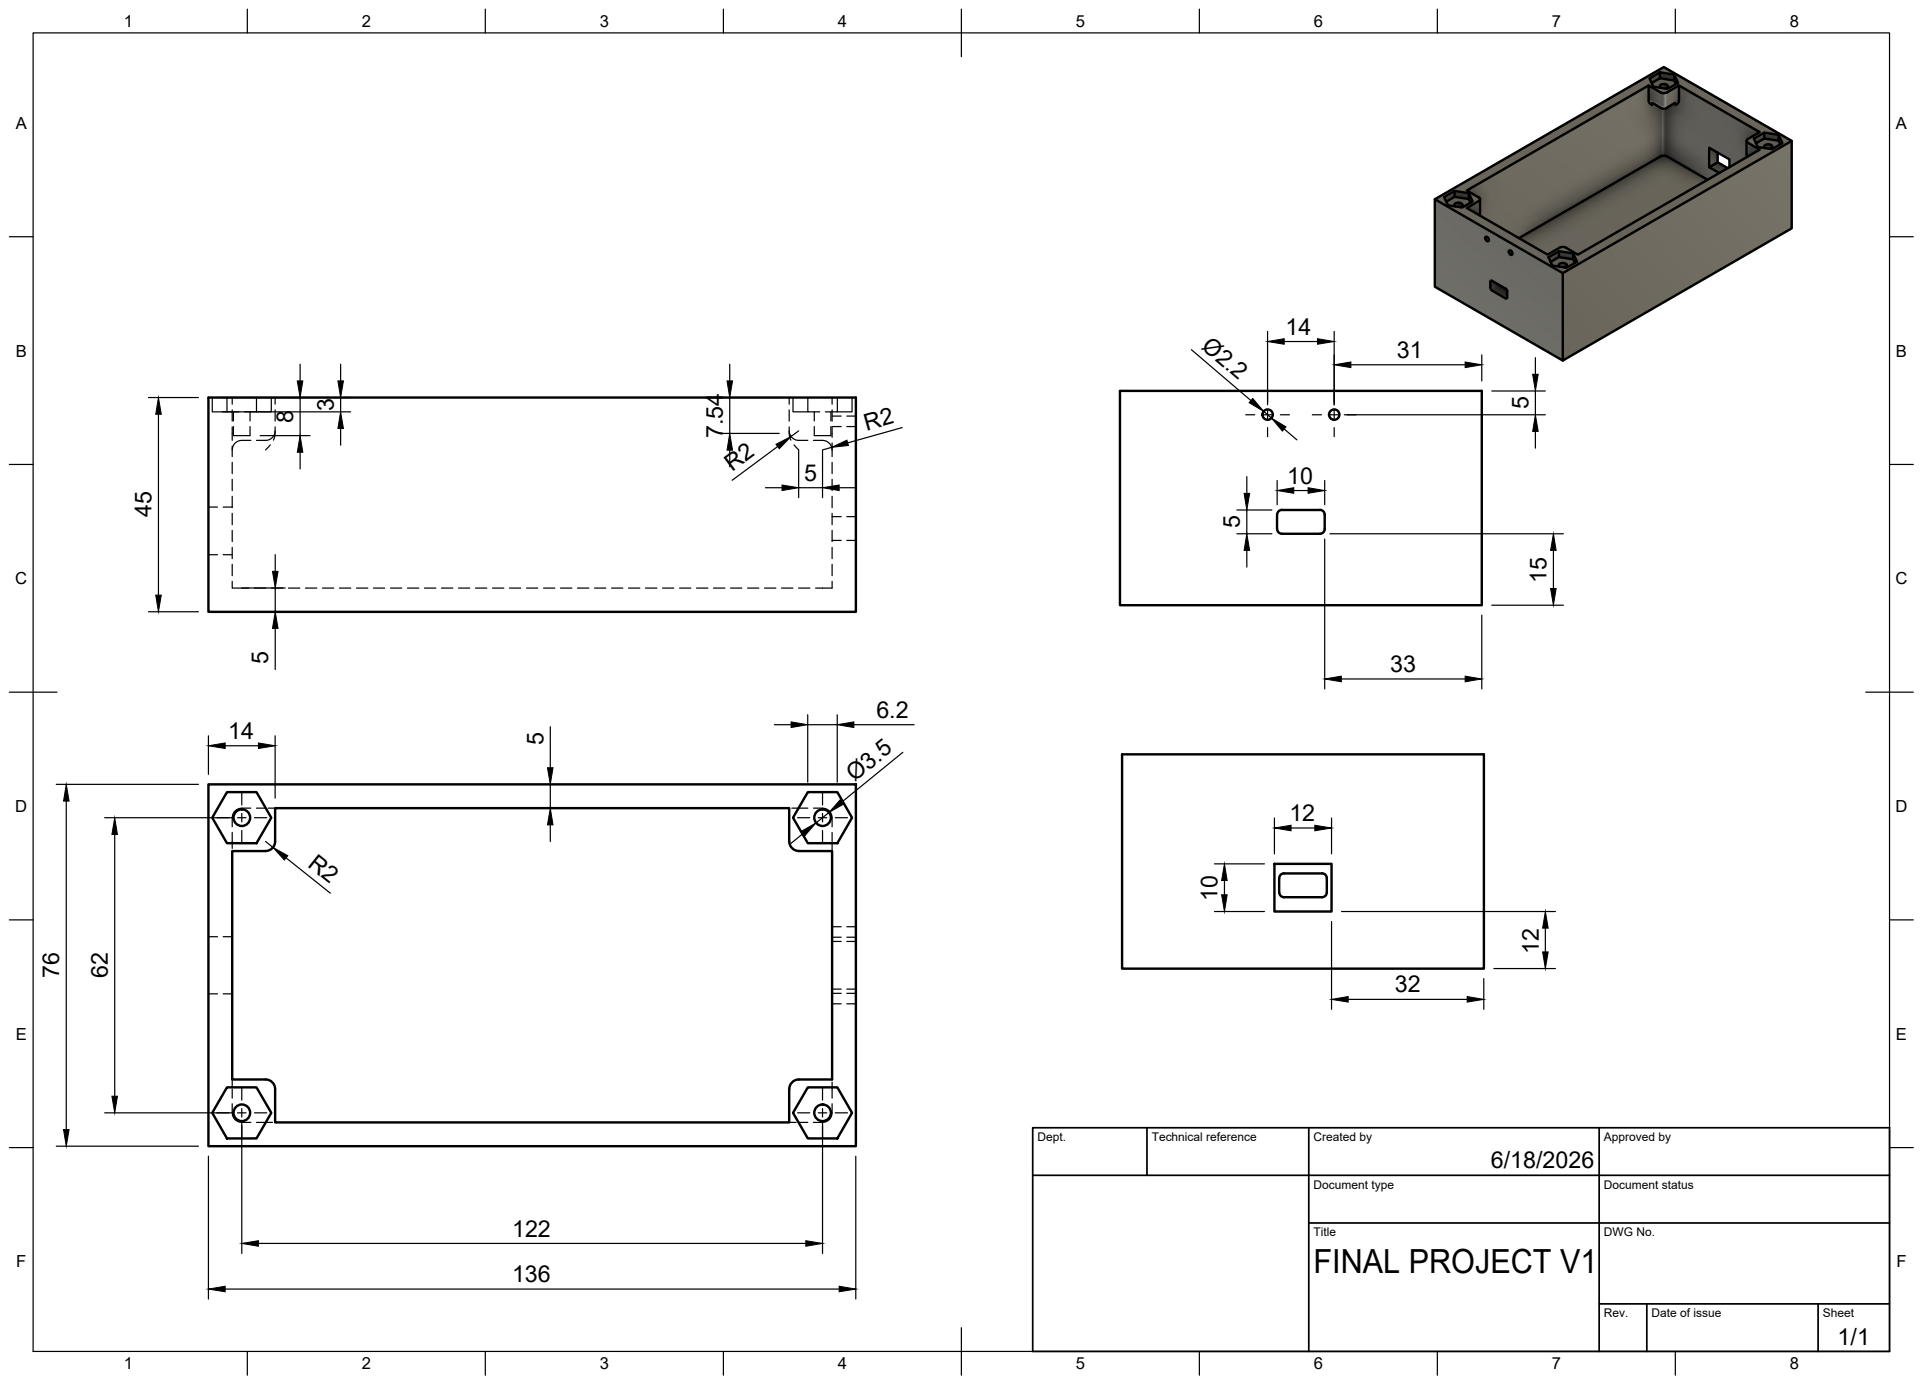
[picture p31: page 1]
Title; DWG No.; Rev.; Date of issue; Sheet

Dept. | Technical reference | Created by 6/18/2026 | Approved by

FINAL PROJECT V1 მმმმ მმმმმმმმმმმ

Document type | Document status

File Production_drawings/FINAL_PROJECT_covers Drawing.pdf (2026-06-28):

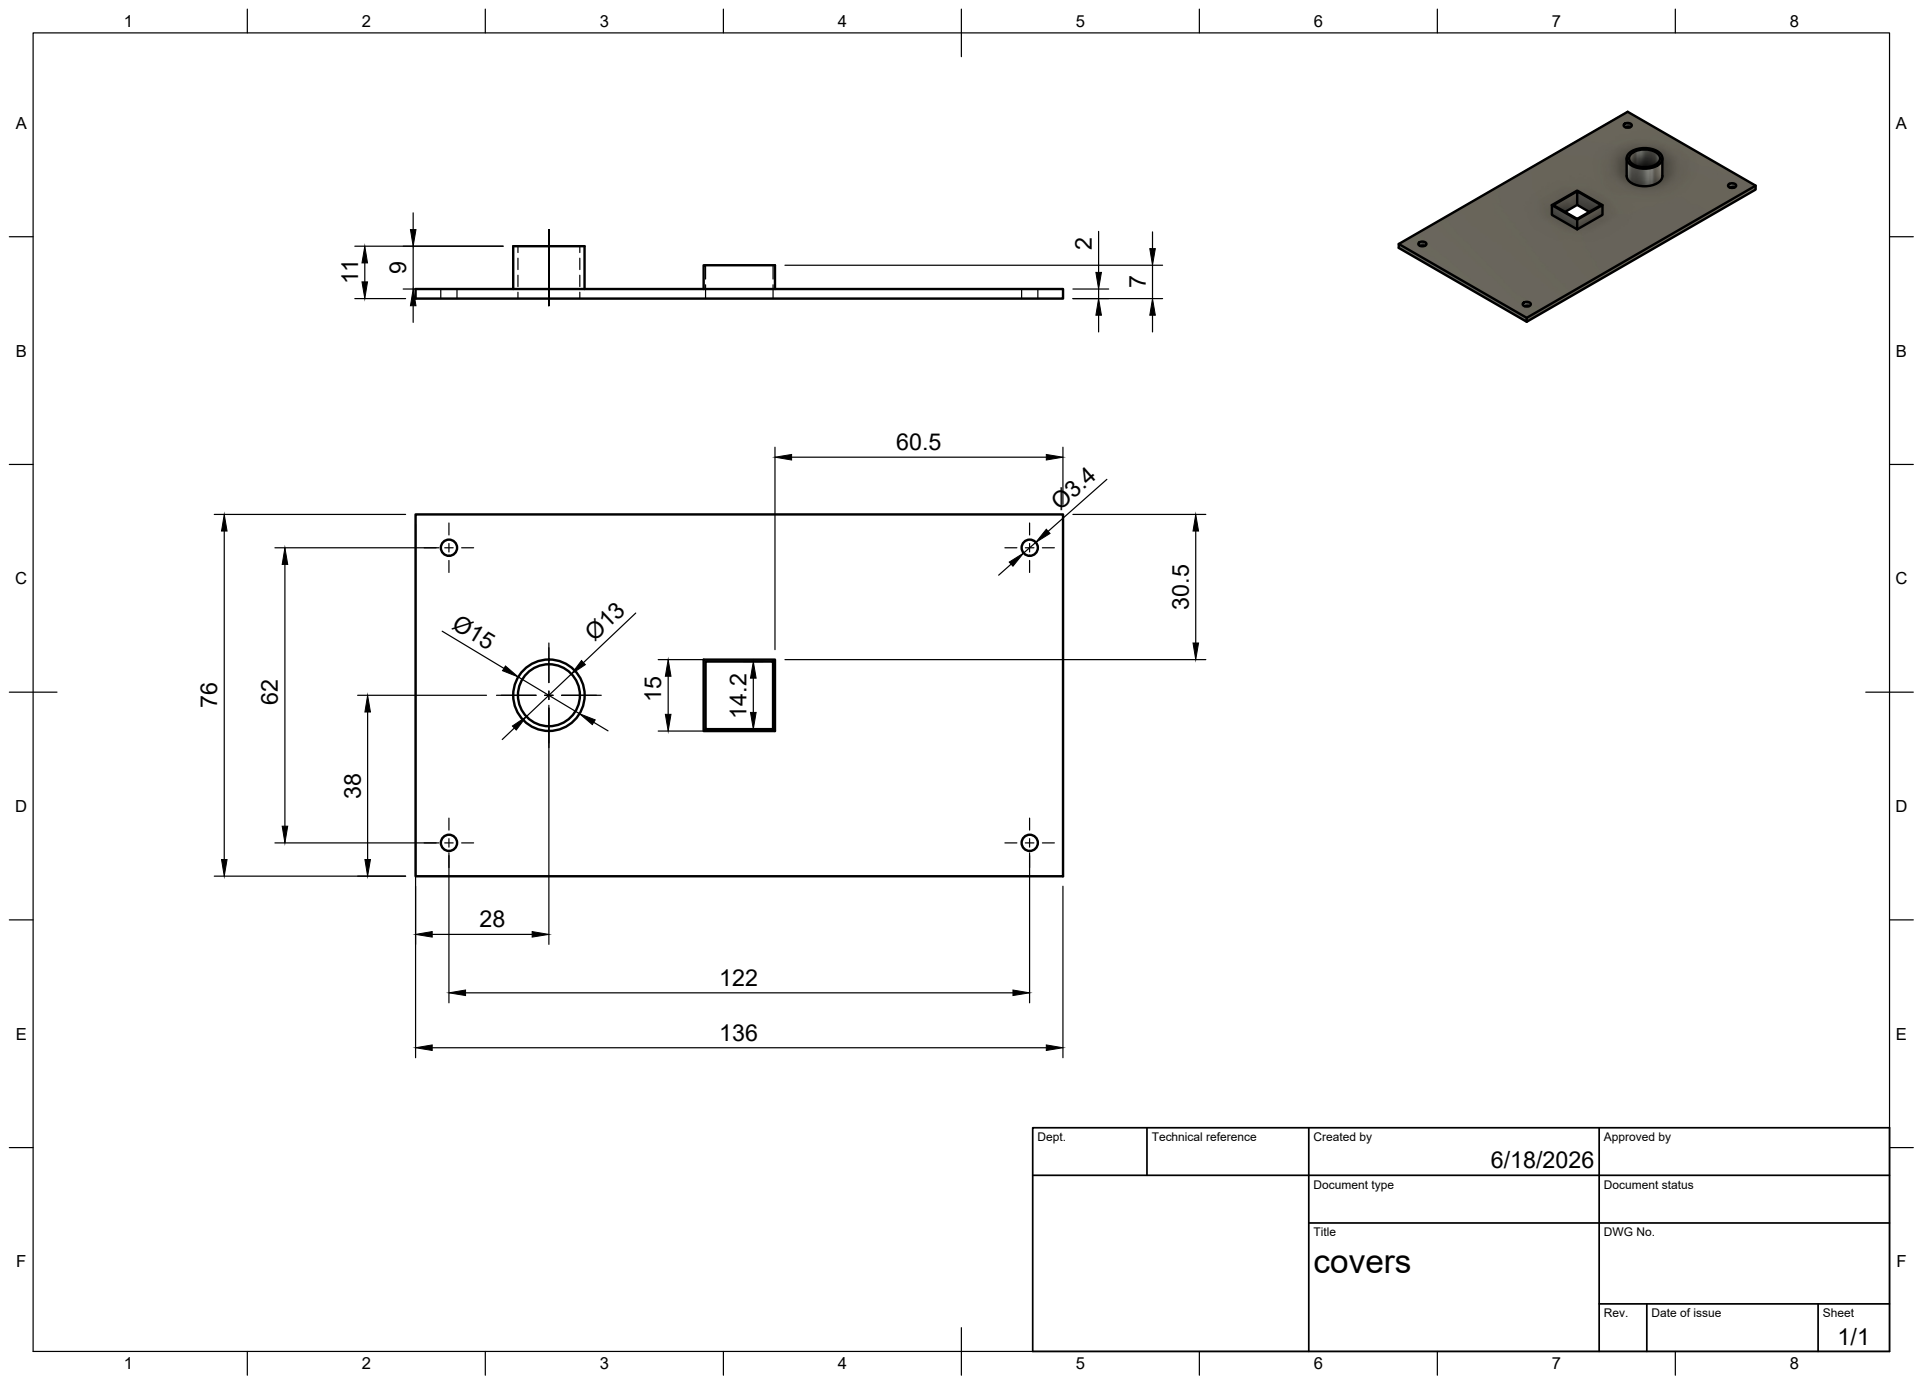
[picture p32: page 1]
Title; DWG No.; Rev.; Date of issue; Sheet

Dept. | Technical reference | Created by 6/18/2026 | Approved by

covers მმმმ მმმმმმმმმმმ

Document type | Document status

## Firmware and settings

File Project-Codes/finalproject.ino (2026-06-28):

#include <Wire.h>
#include <Adafruit_MLX90640.h>
#include <WiFiManager.h>
#include <WiFiClientSecure.h>
#include <UniversalTelegramBot.h>
#include <ArduinoJson.h>

// ──────────────────────────────────────────────────────────────
// THRESHOLDS
// ──────────────────────────────────────────────────────────────

const float FIRE_ON_THRESHOLD  = 80.0f;

const float FIRE_OFF_THRESHOLD = 55.0f;


const int COLD_FRAMES_REQUIRED = 8;

const int   COOLING_FRAMES_REQUIRED  = 10;
const float COOLING_DELTA_THRESHOLD  = -0.2f;

const unsigned long BEEP_INTERVAL_MS = 10000UL;
const unsigned long BEEP_DURATION_MS = 500UL;

const char* TELEGRAM_BOT_TOKEN = "7655520460:AAG239a4LqNq0acoINI3Pn9RyacG_6AhRUc";
String      TELEGRAM_CHAT_ID   = "8154736889";

// ──────────────────────────────────────────────────────────────
// PIN DEFINITIONS
// ──────────────────────────────────────────────────────────────

const int BUZZER_PIN = 4;
const int BUTTON_PIN = 5;
#define I2C_SDA 21
#define I2C_SCL 22

// ──────────────────────────────────────────────────────────────
// SYSTEM STATES
// ──────────────────────────────────────────────────────────────

enum SystemState { STATE_IDLE, STATE_MONITORING, STATE_FIRE_ACTIVE, STATE_ALARM };

static SystemState  currentState = STATE_IDLE;
static portMUX_TYPE stateMux     = portMUX_INITIALIZER_UNLOCKED;

inline SystemState getState() {
    SystemState s;
    portENTER_CRITICAL(&stateMux);
    s = currentState;
    portEXIT_CRITICAL(&stateMux);
    return s;
}

inline void setState(SystemState s) {
    portENTER_CRITICAL(&stateMux);
    currentState = s;
    portEXIT_CRITICAL(&stateMux);
}

// ──────────────────────────────────────────────────────────────
// FREERTOS QUEUES
// ──────────────────────────────────────────────────────────────

QueueHandle_t tempQueue;

struct AlertData { float temp; };
QueueHandle_t alertQueue;

// ──────────────────────────────────────────────────────────────
// GLOBALS
// ──────────────────────────────────────────────────────────────

Adafruit_MLX90640 mlx;
static float sensorFrame[32 * 24];

int           coldFrameCount  = 0;
unsigned long lastAlertTime   = 0;
bool          buzzerActive    = false;
unsigned long buzzerStartTime = 0;
int           lastRawButton    = HIGH;
int           confirmedButton  = HIGH;
unsigned long lastDebounceTime = 0;
const unsigned long DEBOUNCE_MS = 20;
float peakTemp = 0;

float previousTemp  = 0.0f;
int   coolingFrames = 0;


// ──────────────────────────────────────────────────────────────
// FORWARD DECLARATIONS
// ──────────────────────────────────────────────────────────────

void setupWiFi();
void triggerAlert(float maxTemp);
void startBuzzer();
void stopBuzzer();
void updateBuzzer();
bool handleButton();
void telegramTask(void* parameter);
void sensorTask(void* parameter);

// ──────────────────────────────────────────────────────────────
// SETUP
// ──────────────────────────────────────────────────────────────

void setup() {
    Serial.begin(115200);
    delay(500);
    Serial.println("\n=== Gas Stove Fire-Loss Alarm ===");

    pinMode(BUZZER_PIN, OUTPUT);
    digitalWrite(BUZZER_PIN, LOW);
    pinMode(BUTTON_PIN, INPUT_PULLUP);

    tempQueue  = xQueueCreate(1, sizeof(float));
    alertQueue = xQueueCreate(1, sizeof(AlertData));

    Serial.println("[HARDWARE] Clearing potentially locked I2C bus...");
    pinMode(I2C_SDA, INPUT_PULLUP);
    pinMode(I2C_SCL, OUTPUT);
    for (int i = 0; i < 9; i++) {
        digitalWrite(I2C_SCL, LOW);  delayMicroseconds(10);
        digitalWrite(I2C_SCL, HIGH); delayMicroseconds(10);
    }
    Serial.println("[HARDWARE] I2C recovery complete.");

    Wire.setPins(I2C_SDA, I2C_SCL);
    #if defined(ESP32)
        Wire.setBufferSize(2048);
    #endif
    Wire.begin();
    Wire.setClock(400000);

    Wire.beginTransmission(0x33);
    Wire.write(0x80); 
    Wire.write(0x0D);
    Wire.write(0x19); 
    Wire.write(0x01);
    Wire.endTransmission();

    if (!mlx.begin(MLX90640_I2CADDR_DEFAULT, &Wire)) {
        Serial.println("[FATAL] MLX90640 not found! Halted.");
        while (1) delay(10);
    }

    mlx.setMode(MLX90640_CHESS);
    mlx.setResolution(MLX90640_ADC_18BIT);
    mlx.setRefreshRate(MLX90640_2_HZ);
    Wire.setClock(800000);

    Serial.println("[OK] MLX90640 ready.");
    Serial.printf("     Fire ON  threshold : %.0f°C\n", FIRE_ON_THRESHOLD);
    Serial.printf("     Fire OFF threshold : %.0f°C\n", FIRE_OFF_THRESHOLD);
    Serial.printf("     Cold frames needed : %d (~%.0f sec)\n",
                  COLD_FRAMES_REQUIRED, COLD_FRAMES_REQUIRED / 2.0f);
    Serial.printf("     Cooling frames needed : %d (~%.0f sec)\n",
                  COOLING_FRAMES_REQUIRED, COOLING_FRAMES_REQUIRED / 2.0f);

    lastRawButton   = digitalRead(BUTTON_PIN);
    confirmedButton = lastRawButton;

    setupWiFi();

    xTaskCreatePinnedToCore(sensorTask,   "SensorTask",   4096, NULL, 3, NULL, 1);
    xTaskCreatePinnedToCore(telegramTask, "TelegramTask", 8192, NULL, 1, NULL, 0);

    Serial.println("[OK] Setup complete. Press button to start monitoring.");
}

// ──────────────────────────────────────────────────────────────
// MAIN LOOP
// ──────────────────────────────────────────────────────────────

void loop() {
    updateBuzzer();

    if (handleButton()) {
        stopBuzzer();

        SystemState next = (getState() == STATE_IDLE) ? STATE_MONITORING : STATE_IDLE;
        setState(next);

        coldFrameCount = 0;
        lastAlertTime  = 0;
        xQueueReset(tempQueue);
        xQueueReset(alertQueue);

        if (next == STATE_IDLE) {
            previousTemp  = 0.0f;
            coolingFrames = 0;
        }

        Serial.println(next == STATE_MONITORING
            ? "[BUTTON] Monitoring STARTED. Waiting for flame..."
            : "[BUTTON] System STOPPED.");

        vTaskDelay(50 / portTICK_PERIOD_MS);
        return;
    }

    if (getState() == STATE_IDLE) {
        vTaskDelay(5 / portTICK_PERIOD_MS);
        return;
    }

    float maxTemp;
    if (xQueueReceive(tempQueue, &maxTemp, 0) != pdTRUE) {
        vTaskDelay(5 / portTICK_PERIOD_MS);
        return;
    }

    switch (getState()) {

        case STATE_MONITORING: {
            Serial.printf("[MONITOR] Max: %.1f°C | Fire trigger: %.0f°C\n",
                          maxTemp, FIRE_ON_THRESHOLD);

            if (maxTemp >= FIRE_ON_THRESHOLD) {
                setState(STATE_FIRE_ACTIVE);
                coldFrameCount = 0;
                coolingFrames  = 0;
                previousTemp   = maxTemp;
                peakTemp       = maxTemp;
                Serial.printf("[EVENT] Flame detected! %.1f°C >= %.0f°C\n",
                              maxTemp, FIRE_ON_THRESHOLD);
            }
            break;
        }

        case STATE_FIRE_ACTIVE: {
            if (maxTemp > peakTemp) peakTemp = maxTemp;

            float delta = maxTemp - previousTemp;

            if (delta <= COOLING_DELTA_THRESHOLD) {
                coolingFrames++;
            } else {
                coolingFrames = 0;
            }

            previousTemp = maxTemp;

            Serial.printf("[FIRE] Max: %.1f°C | dT: %+.2f°C | Lost below: %.0f°C | Cold frames: %d/%d | Cooling frames: %d/%d\n",
                          maxTemp, delta, FIRE_OFF_THRESHOLD,
                          coldFrameCount, COLD_FRAMES_REQUIRED,
                          coolingFrames,  COOLING_FRAMES_REQUIRED);

            if (maxTemp < FIRE_OFF_THRESHOLD) {
                coldFrameCount++;
                if (coldFrameCount >= COLD_FRAMES_REQUIRED) {
                    setState(STATE_ALARM);
                    lastAlertTime = millis();
                    startBuzzer();
                    triggerAlert(maxTemp);
                    Serial.printf("[ALARM] Flame gone! Temp dropped to %.1f°C\n", maxTemp);
                }
            } else {
                if (coldFrameCount > 0) {
                    Serial.println("[EVENT] Still hot — cold frame counter reset.");
                    coldFrameCount = 0;
                }
            }

            if (coolingFrames >= COOLING_FRAMES_REQUIRED) {
                setState(STATE_ALARM);
                lastAlertTime = millis();
                startBuzzer();
                triggerAlert(maxTemp);
                Serial.printf("[ALARM] Sustained cooling detected! dT trend over %d frames. Temp: %.1f°C\n",
                              COOLING_FRAMES_REQUIRED, maxTemp);
            }

            break;
        }

        case STATE_ALARM: {
            unsigned long now = millis();
            if (now - lastAlertTime >= BEEP_INTERVAL_MS) {
                lastAlertTime = now;
                startBuzzer();
                triggerAlert(maxTemp);
            }
            break;
        }

        default: break;
    }

    vTaskDelay(5 / portTICK_PERIOD_MS);
}

// ──────────────────────────────────────────────────────────────
// SENSOR TASK — Core 1
// ──────────────────────────────────────────────────────────────

void sensorTask(void* parameter) {
    while (true) {
        if (getState() == STATE_IDLE) {
            vTaskDelay(50 / portTICK_PERIOD_MS);
            continue;
        }

        if (mlx.getFrame(sensorFrame) != 0) {
            Serial.println("[SENSOR] Frame read failed – retrying.");
            vTaskDelay(20 / portTICK_PERIOD_MS);
            continue;
        }

        float maxT = sensorFrame[0];
        for (int i = 1; i < 32 * 24; i++)
            if (sensorFrame[i] > maxT) maxT = sensorFrame[i];

        xQueueReset(tempQueue);
        xQueueSend(tempQueue, &maxT, 0);

        vTaskDelay(10 / portTICK_PERIOD_MS);
    }
}

// ──────────────────────────────────────────────────────────────
// TELEGRAM TASK — Core 0
// ──────────────────────────────────────────────────────────────

void telegramTask(void* parameter) {
    AlertData alert;
    while (true) {
        if (xQueueReceive(alertQueue, &alert, 0) == pdTRUE) {
            if (WiFi.status() == WL_CONNECTED) {
                WiFiClientSecure localClient;
                localClient.setInsecure();
                UniversalTelegramBot bot(TELEGRAM_BOT_TOKEN, localClient);

                String message = "🚨 *Gas Stove Alarm!*\n";
                message += "The flame has gone out unexpectedly.\n";
                message += "Last temperature reading: *" + String(alert.temp, 1) + " °C*\n";
                message += "⚠️ Check the stove immediately — possible gas leak risk!";

                Serial.println("[Telegram] Sending alert…");
                bot.sendMessage(TELEGRAM_CHAT_ID, message, "Markdown");
                Serial.println("[Telegram] Alert sent.");
            } else {
                Serial.println("[Telegram] Skipped – no Wi-Fi.");
            }
        }
        vTaskDelay(50 / portTICK_PERIOD_MS);
    }
}

// ──────────────────────────────────────────────────────────────
// HELPERS
// ──────────────────────────────────────────────────────────────

void triggerAlert(float maxTemp) {
    AlertData alert = { maxTemp };
    xQueueReset(alertQueue);
    xQueueSend(alertQueue, &alert, 0);
}

bool handleButton() {
    int rawReading = digitalRead(BUTTON_PIN);
    if (rawReading != lastRawButton) {
        lastDebounceTime = millis();
        lastRawButton    = rawReading;
    }
    if ((millis() - lastDebounceTime) >= DEBOUNCE_MS) {
        if (rawReading != confirmedButton) {
            confirmedButton = rawReading;
            if (confirmedButton == LOW) return true;
        }
    }
    return false;
}

void startBuzzer() {
    Serial.println("[BUZZER] Beep start.");
    digitalWrite(BUZZER_PIN, HIGH);
    buzzerActive    = true;
    buzzerStartTime = millis();
}

void stopBuzzer() {
    digitalWrite(BUZZER_PIN, LOW);
    buzzerActive = false;
}

void updateBuzzer() {
    if (buzzerActive && (millis() - buzzerStartTime >= BEEP_DURATION_MS)) {
        stopBuzzer();
        Serial.println("[BUZZER] Beep end.");
    }
}

void setupWiFi() {
    WiFiManager wm;
    std::vector<const char*> menu = {"wifi"};
    wm.setMenu(menu);
    wm.setTitle("Configure Device");
    wm.setConfigPortalTimeout(600);

    WiFiManagerParameter custom_chat_id("chat", "Telegram Chat ID", "", 30);
    wm.addParameter(&custom_chat_id);

    Serial.println("[WiFi] Attempting connection…");
    if (wm.autoConnect("ThermalSystemSetup")) {
        String entered = String(custom_chat_id.getValue());
        if (entered.length() > 0) TELEGRAM_CHAT_ID = entered;
        Serial.printf("[WiFi] Connected! IP: %s\n", WiFi.localIP().toString().c_str());
    } else {
        Serial.println("[WiFi] No Wi-Fi – running offline.");
    }
}
